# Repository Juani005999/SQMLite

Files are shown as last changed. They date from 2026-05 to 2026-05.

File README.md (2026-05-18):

# SQMLite

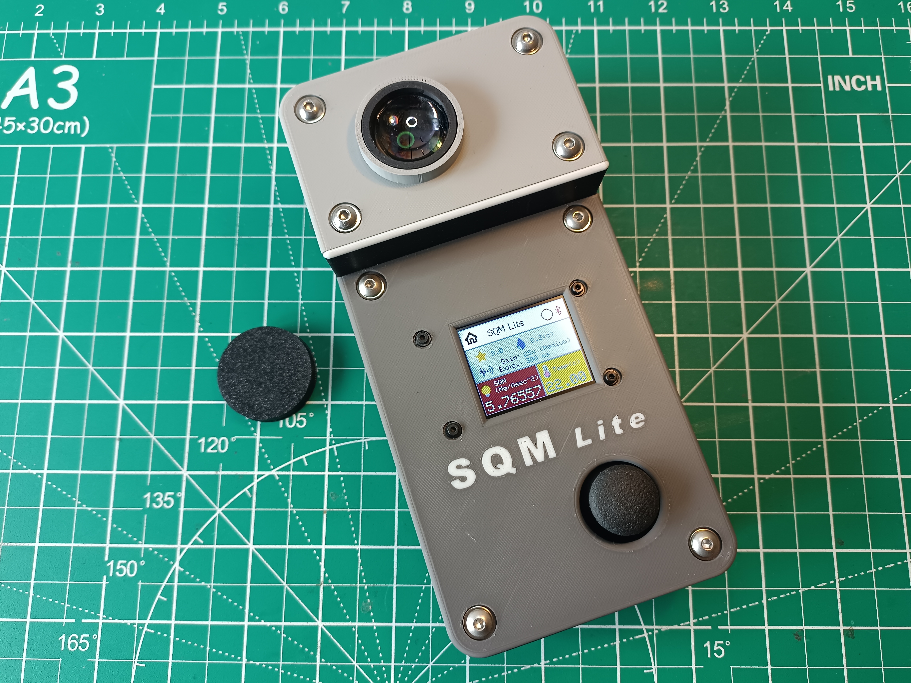
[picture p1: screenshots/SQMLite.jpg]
SQM Lite


## Sommaire
- [Description](#description)
    - [Fonctionnalités](#fonctionnalités)
    - [Echelle de Bortle](#echelle-de-bortle)
- [Liste des pièces](#liste-des-pièces)
    - [Amazon](#amazon)
    - [Ali Express](#ali-express)
    - [Visserie & Divers](#visserie--divers)
- [Montage](#montage)
    - [Breadboard](#breadboard)
    - [PCB](#pcb)
    - [Boxes](#boxes)
    - [ESP32](#esp32)
    - [Capteurs](#capteurs)
    - [Optique du TSL2591](#optique-du-tsl2591)
- [Firmware](#firmware)
    - [Bibliothèques nécessaires à l'application](#bibliothèques-nécessaires-à-lapplication)
    - [Sélection de la carte](#sélection-de-la-carte)
    - [Paramètres de l'application dans Arduino IDE](#paramètres-de-lapplication-dans-arduino-ide)
    - [Configuration de l'application](#configuration-de-lapplication)
    - [Configuration de l'écran TFT ST7735](#configuration-de-lécran-tft-st7735)
    - [Implémentation](#implémentation)
    - [Mode \"Debug\"](#mode-debug)
- [Utilisation](#utilisation)
    - [Matériel](#matériel)
    - [Calibration](#calibration)
    - [Mise en veille](#mise-en-veille)
    - [Logiciel](#logiciel)
        - [En-tête](#en-tête)
        - [Ecran d'accueil](#ecran-daccueil)
        - [Ecran Luminosité](#ecran-luminosité)
        - [Ecran Environnement](#ecran-environnement)
- [Driver ASCOM](#driver-ascom)
    - [Installation](#installation)
    - [Détection du périphérique bluetooth dans Windows](#détection-du-périphérique-bluetooth-dans-windows)
    - [Utilisation dans NINA](#utilisation-dans-nina)
        - [Sélection du SQMLite dans NINA](#sélection-du-sqmlite-dans-nina)
        - [Première utilisation dans NINA](#première-utilisation-dans-nina)
- [Retex](#retex)
- [Révisions](#révisions)

## Description
Le **SQM Lite** est un Sky Quality Meter (SQM) DIY (Do It Yourself) contenant les composants suivant :
- TSL2591
- BME280
- TFT ST7735

Ce modèle est basé sur le [**ROM V2**](https://github.com/Juani005999/ROMV2), sans le GPS, l'accéléromètre et la lecture de la température du ciel.

<p align="right"><a href="#sommaire">Retour au sommaire</a></p>

### Fonctionnalités

- Lecture de la luminosité (full / ir / visible), calcul de la quantité de Lux, du SQM et du Bortle.
- Lecture de la luminosité dans une tâche dédiée FreeRTOS s'exécutant en paralèlle sur le 2ème coeur de l'ESP 32.
- Correction thermique de la lecture du Lux en fonction de la température ambiante.
- Moyenne mobile du Lux sur 50 valeurs permettant de réduire l'incertitude mesurée. Calcul du SQM et du Bortle sur la moyenne mobile du Lux.
- Possibilité de remise à zéro de la moyenne mobile.
- Réglage automatique de la sensibilité (1x, 25x, 428x, 9876x) et de la durée de mesure (100ms, 200ms, 300ms, 400ms, 500ms, 600ms) du capteur de luminosité TSL2591.
- Lecture des conditions d'environnement (température, taux d'humidité, pression atmosphérique) via le capteur BME280.
- Calcul du point de rosée.
- Connection Bluetooth BLE.
- Driver ASCOM permettant de se connecter via Bluetooth BLE.
- Indicateur de mesure de luminosité en cours.
- Indicateur d'état d'une connection Bluetooth BLE client.
- Indicateur de charge restante dans la batterie.
- Mise en veille de l'écran après 5 minutes d'inactivité ou sur demande.

<p align="right"><a href="#sommaire">Retour au sommaire</a></p>

### Echelle de Bortle

Voici l'échelle de Bortle utilisée dans l'application.

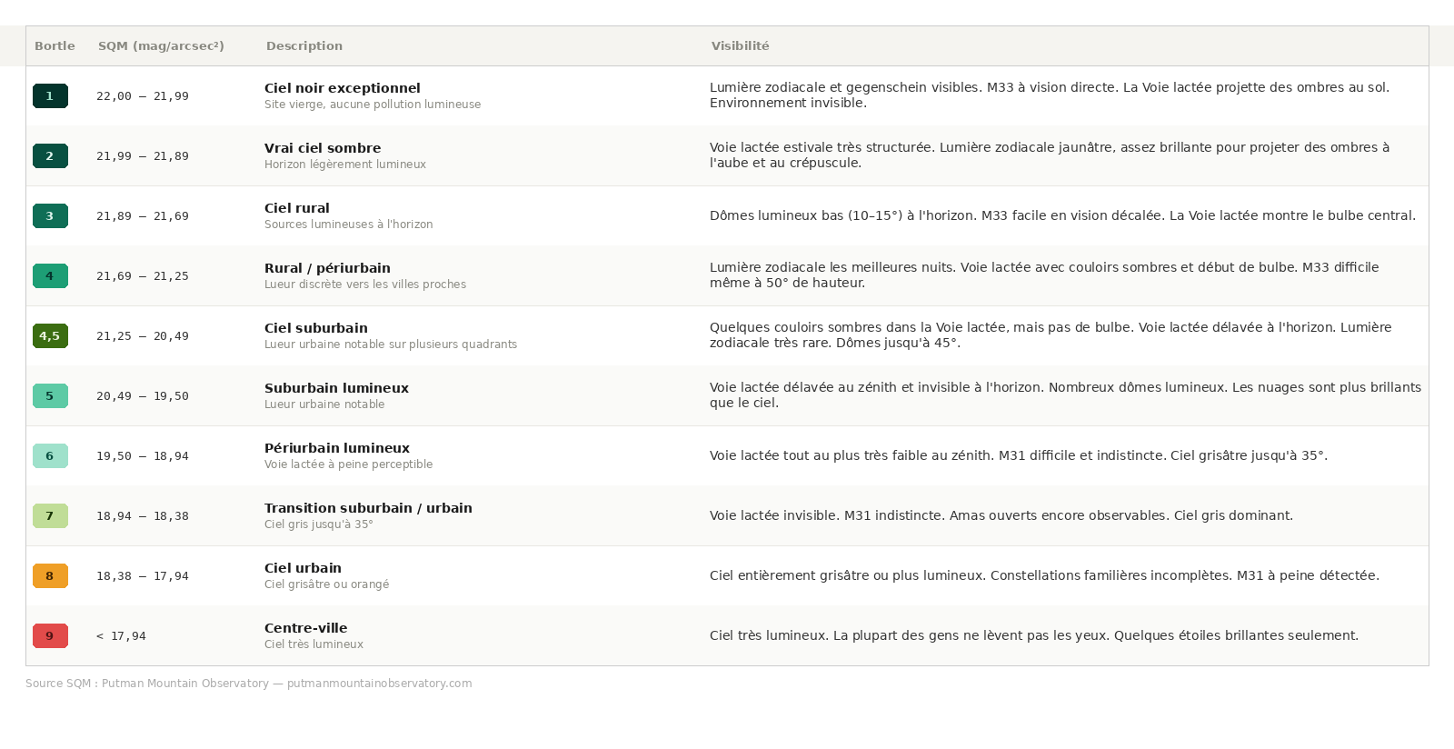
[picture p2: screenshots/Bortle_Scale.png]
Bortle Scale


<p align="right"><a href="#sommaire">Retour au sommaire</a></p>

## Liste des pièces
### Amazon

| Composant | Prix | Nb. pièces | Prix unitaire |
| --- | --- | --- | --- |
| ESP32 with Battery (USB-C) | 18.77 € | 1 | 18.77 € |
| [TSL2591](https://www.amazon.fr/dp/B0GGD3FNKM) | 12.69 € | 1 | 12.69 € |
| [BME280](https://www.amazon.fr/dp/B07HMQMW6M) | 39.48 € | 5 | 7.90 € |
| [TFT ST7735](https://www.amazon.fr/AZDelivery-TFT-Compatible-Raspberry-incluant/dp/B07TJGF8HS) | 27.99 € | 5 | 5.60 € |
| [Lentille D23 F30](https://www.amazon.fr/Lentille-biconvexe-Double-Convexe-Optique/dp/B0GVHDZD22) | 25.94 € | 1 | 25.94 € |
| [Joystick](https://www.amazon.fr/Gebildet-Joystick-Commande-Contr%C3%B4leur-Raspberry/dp/B0DPMN19G6) | 10.99 € | 8 | 1.37 € |
| [Boot Button](https://www.amazon.fr/dp/B07S1MNB8C) | 10.99 € | 5 | 2.20 € |
| [Interrupteur à bascule](https://www.amazon.fr/dp/B076VKRKQQ) | 7.49 € | 5 | 1.50 € |
| [Rallonge USB-C](https://www.amazon.fr/Cablecc-3-1-type-femelle-donn%C3%A9es-dextension/dp/B075P2FF7L) | 17.56 € | 1 | 17.56 € |
| [Testeur de capacité](https://www.amazon.fr/dp/B0DKHT664R) | 12.79 € | 4 | 3.20 € |
| | | Total | **96.73 €** |

<p align="right"><a href="#sommaire">Retour au sommaire</a></p>

### Ali Express
| Composant | Prix | Nb. pièces | Prix unitaire |
| --- | --- | --- | --- |
| [ESP32 with Battery (USB-C)](https://fr.aliexpress.com/item/1005007579177706.html) | 5.09 € | 1 | 5.09 € |
| [TSL2591](https://fr.aliexpress.com/item/1005009222536594.html) | 3.79 € | 1 | 3.79 € |
| [BME280](https://fr.aliexpress.com/item/1005010256393146.html) | 4.59 € | 1 | 4.59 € |
| [TFT ST7735](https://fr.aliexpress.com/item/1005008974306385.html) | 3.29 € | 1 | 3.29 € |
| [Lentille D23 F30](https://fr.aliexpress.com/item/1005007033633969.html) | 2.33 € | 1 | 2.33 € |
| [Joystick](https://fr.aliexpress.com/item/1005009009852719.html) | 0.46 € | 1 | 0.46 € |
| [Boot Button](https://fr.aliexpress.com/item/1005007876916629.html) | 26.19 € | 20 | 1.31 € |
| [Interrupteur à bascule](https://fr.aliexpress.com/item/1005010311259797.html) | 1.79 € | 10 | 0.18 € |
| [Rallonge USB-C 0.2m](https://fr.aliexpress.com/item/1005005292730047.html) | 1.71 € | 1 | 1.71 € |
| [Testeur de capacité](https://fr.aliexpress.com/item/1005006350742151.html) | 1.45 € | 1 | 1.45 € |
| | | Total | **24.20 €** |

<p align="right"><a href="#sommaire">Retour au sommaire</a></p>

### Visserie & Divers

| Composant | Propriétés | Quantité |
| --- | --- | --- |
| Vis & rondelles | M4 x 20mm | 8 |
| Vis & rondelles | M2 x 20mm | 4 |
| Vis & rondelles | M2 x 8mm | 21 |
| Vis & rondelles | M2 x 6mm | 8 |
| Ecrou Nylstop autobloquants | M2 | 7 |
| [PCB EPLZON](https://www.amazon.fr/dp/B0B5DCHM7K) | ... | 1 |
| [Câbles Dupont](https://www.amazon.fr/Breadboard-Jumper-Wires-Dupont-Cable/dp/B0BTT48V7P) | ... | ... |
| [PCB Vis Connecteur](https://www.amazon.fr/dp/B082ZNRQMJ?th=1) | ... | ... |
| [Jumper Breadboard](https://www.amazon.fr/dp/B0F6LJS4L2?ref=ppx_yo2ov_dt_b_fed_asin_title) | ... | ... |
| [Pile Rechargeable 18650](https://bestpiles.fr/piles-rechargeables-18650/991-pile-rechargeable-18650-inr18650mj1-li-ion-37v-3500mah-10a-8438493099829.html) | Li-ion 3,7V 3500mAh 10A | 1 |

<p align="right"><a href="#sommaire">Retour au sommaire</a></p>

## Montage

Montage

<p align="right"><a href="#sommaire">Retour au sommaire</a></p>

### Breadboard
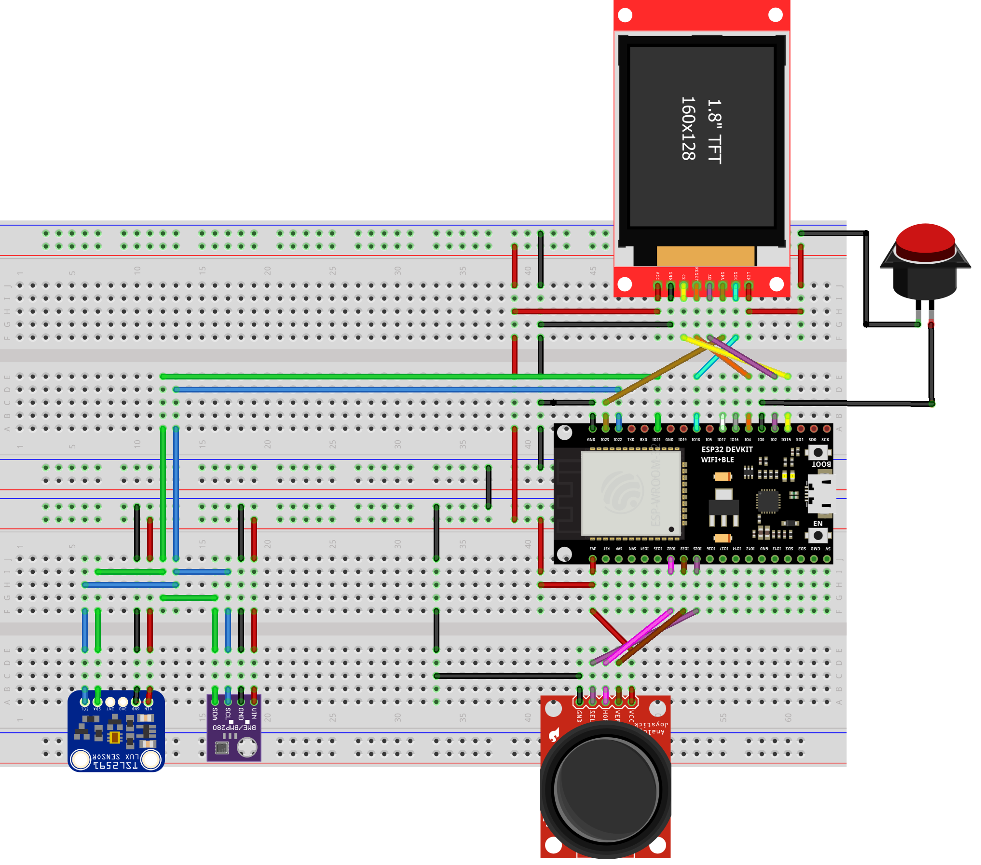
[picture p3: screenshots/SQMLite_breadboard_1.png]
Breadboard


<p align="right"><a href="#sommaire">Retour au sommaire</a></p>

### PCB
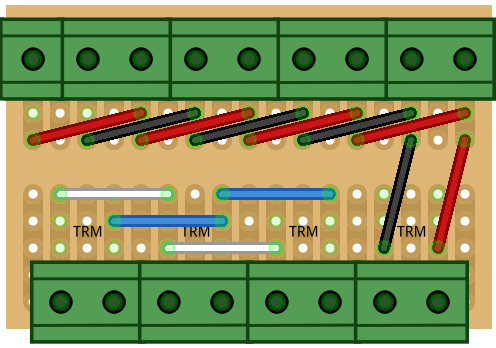
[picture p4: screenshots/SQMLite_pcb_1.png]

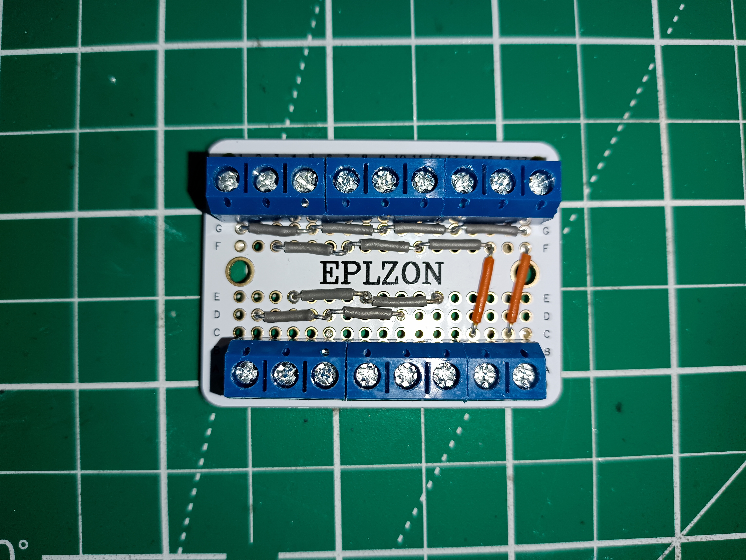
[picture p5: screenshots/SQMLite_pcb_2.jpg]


<p align="right"><a href="#sommaire">Retour au sommaire</a></p>

### Boxes
Vous trouverez dans [ce dossier](./Boxes/) tous les fichiers STL nécessaires à l'impression 3D.

<p align="right"><a href="#sommaire">Retour au sommaire</a></p>

### ESP32
Des branchements direct sur l'ESP32 sont nécessaires :
- 2 câbles Dupont branchés directement sur l'interrupteur de l'ESP et connectés à l'interrupteur du **SQM Lite**.
- 2 câbles branchés sur les pôles + et - de l'ESP et connectés à l'indicateur de charge restante de la batterie.

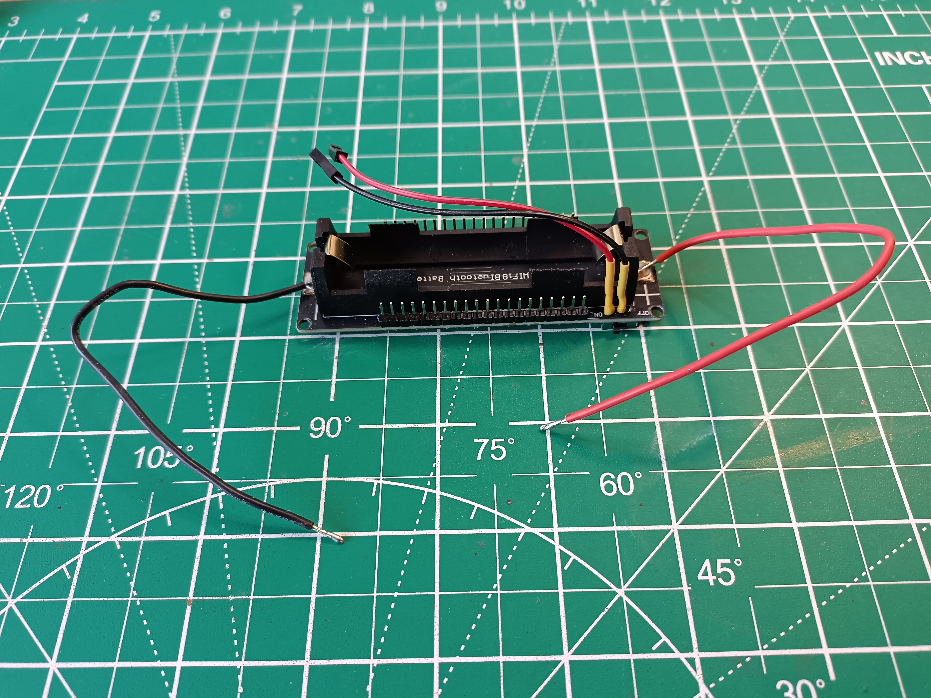
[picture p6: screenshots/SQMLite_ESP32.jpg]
ESP32


> [!WARNING]
> Attention, le connecteur **USB-C** présent sur l'ESP est **très très fragile** (j'en ai personnellement cassé plusieurs sur d'autres projets en faisant des branchements). Je vous conseil donc de rajouter 2 points de soudure de part et d'autre du connecteur  afin d'augmenter sa solidité.

<p align="right"><a href="#sommaire">Retour au sommaire</a></p>

### Capteurs
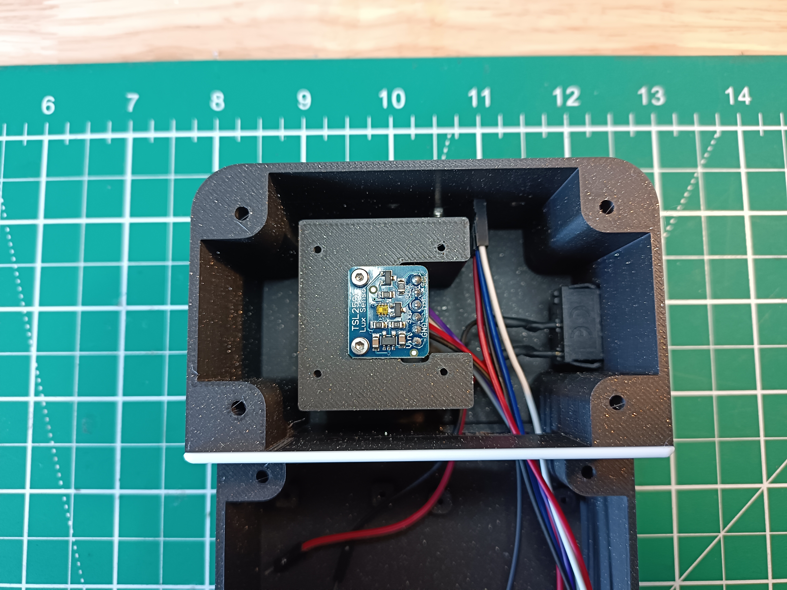
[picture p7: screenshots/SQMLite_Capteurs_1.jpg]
Capteurs

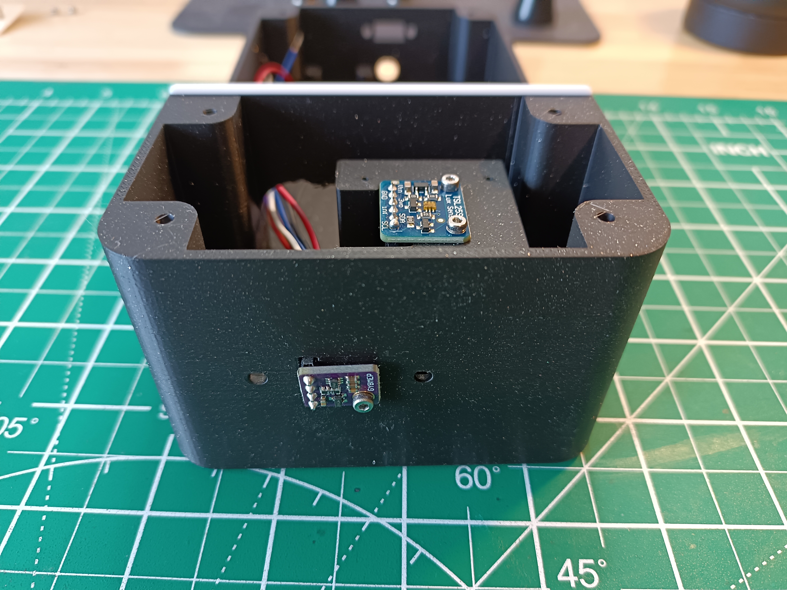
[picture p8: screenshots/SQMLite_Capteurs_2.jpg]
Capteurs

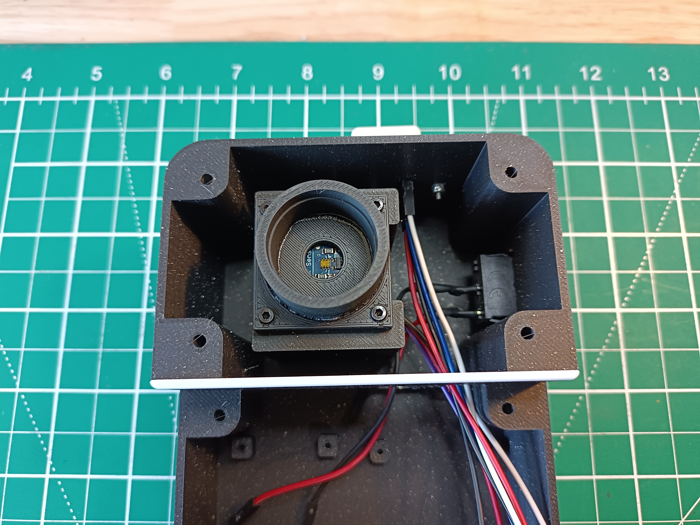
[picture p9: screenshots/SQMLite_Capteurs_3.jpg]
Capteurs

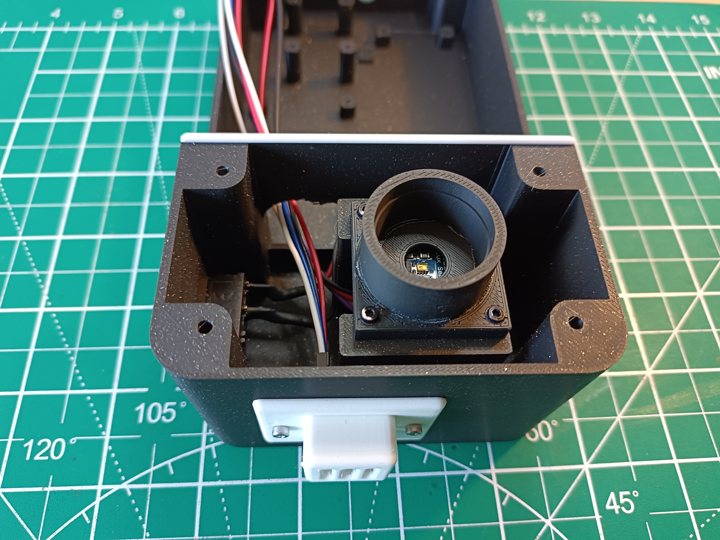
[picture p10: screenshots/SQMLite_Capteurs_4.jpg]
Capteurs


<p align="right"><a href="#sommaire">Retour au sommaire</a></p>

#### Optique du TSL2591
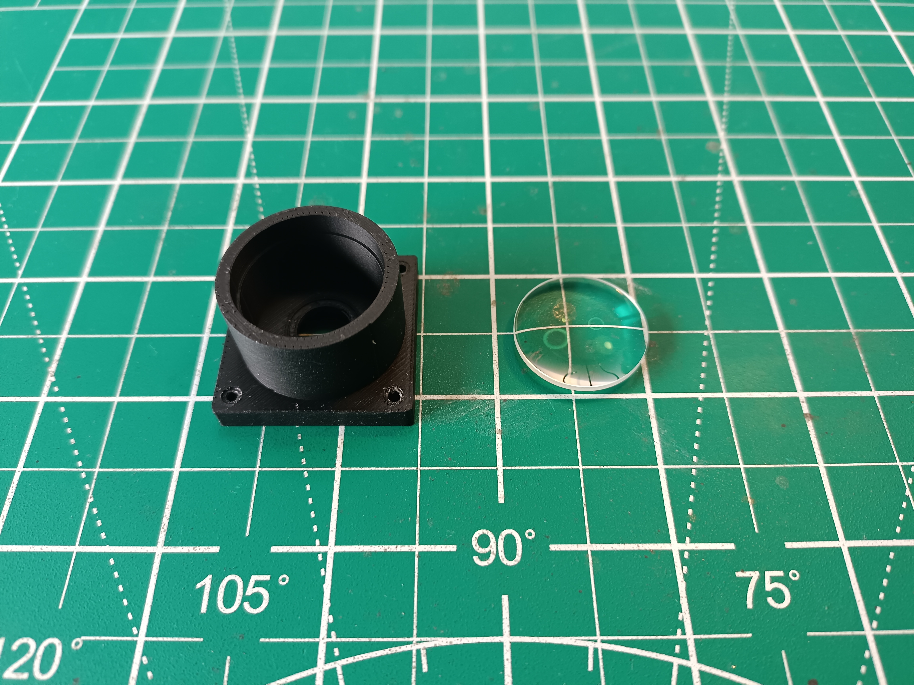
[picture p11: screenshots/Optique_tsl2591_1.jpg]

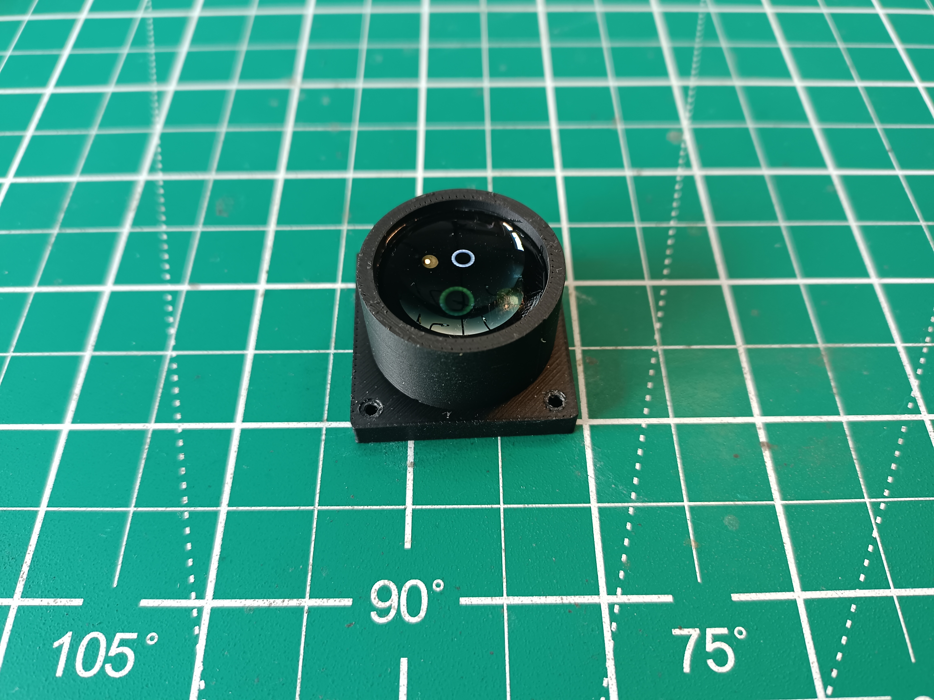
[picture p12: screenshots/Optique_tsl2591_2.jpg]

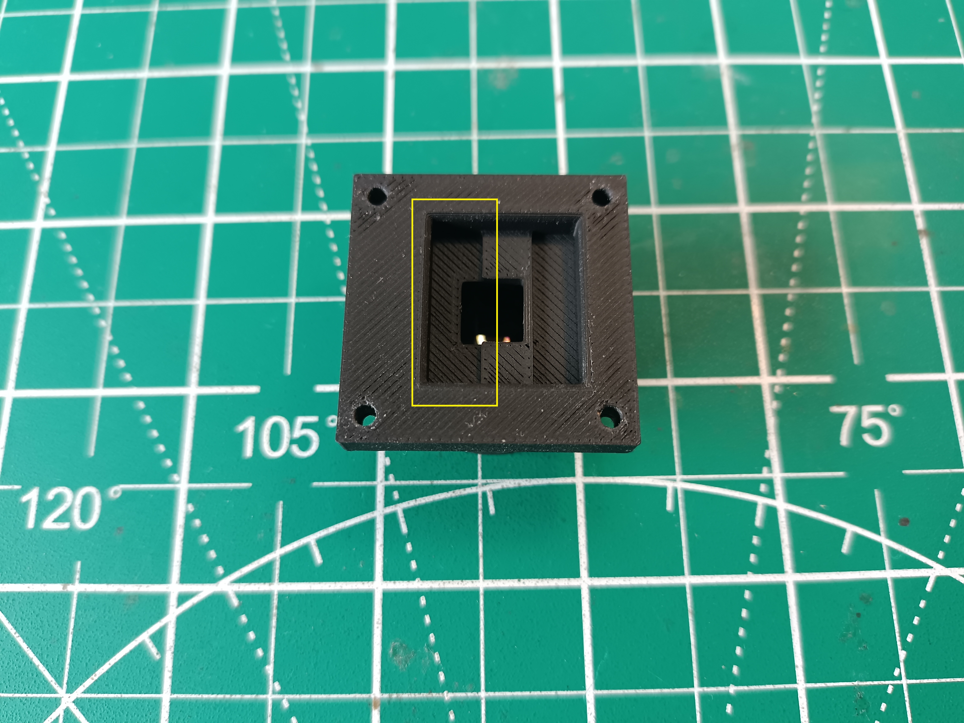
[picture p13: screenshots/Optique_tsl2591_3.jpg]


> [!IMPORTANT]
> La partie encadrée en jaune correspond au côté des vis du TSL2591.

> [!TIP]
> La lentille est optionnelle. Vous pouvez uniquement positionner le cache du capteur et le tube sans la lentille. Vous pourrez ensuite corriger la [calibration](#calibration) si nécessaire.

<p align="right"><a href="#sommaire">Retour au sommaire</a></p>

## Firmware

- Télécharger le fichier **SQMLite_Firmware.zip**
- Depuis votre Arduino IDE, installer la bibliothèque **SQMLite**, en sélectionnant le fichier téléchargé via le menu : \
***Croquis*** -> ***Importer une bibliothèque*** -> ***Ajouter la bibliothèque .ZIP ...***

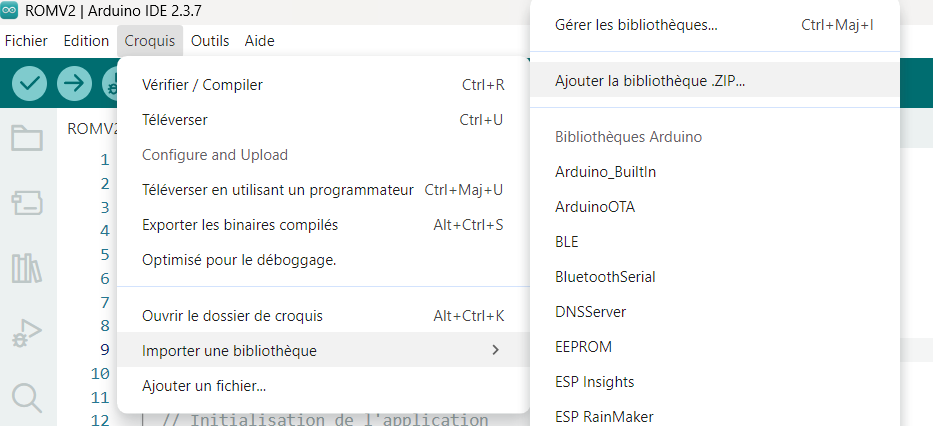
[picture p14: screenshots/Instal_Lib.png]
ROMV2_LIB


<p align="right"><a href="#sommaire">Retour au sommaire</a></p>

### Bibliothèques nécessaires à l'application
Voici la liste des bibliothèques utilisées par l'application que vous devez installer via le gestionnaire de librairies dans votre *Arduino IDE* :

- Adafruit_TSL2591
- Adafruit_BME280
- TFT_eSPI

<p align="right"><a href="#sommaire">Retour au sommaire</a></p>

### Sélection de la carte
Dans votre *Arduino IDE*, sélectionnez la carte **ESP32 Dev Module**.
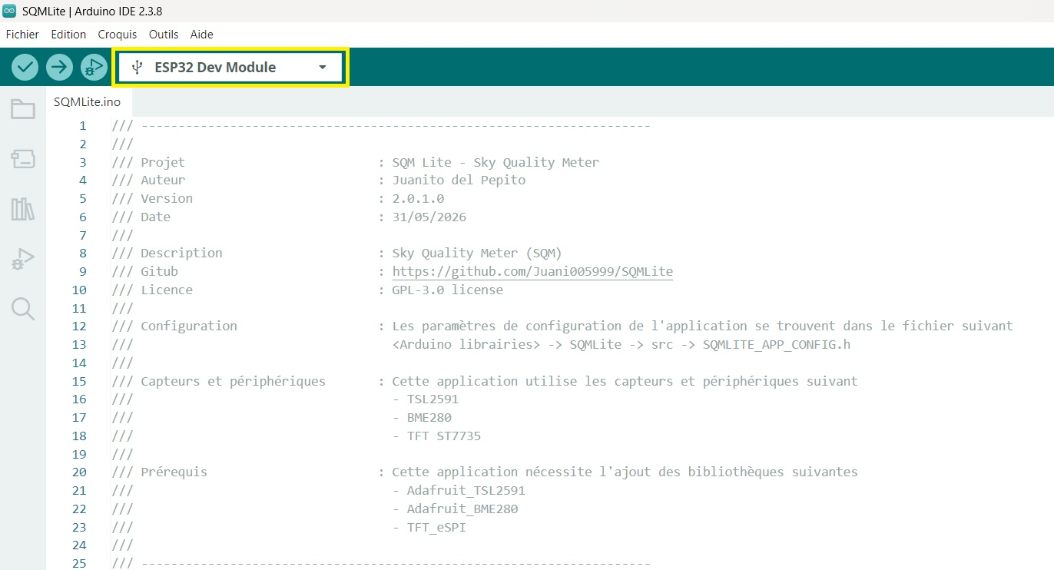
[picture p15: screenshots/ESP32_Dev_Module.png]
ESP32 Dev Module


<p align="right"><a href="#sommaire">Retour au sommaire</a></p>

### Paramètres de l'application dans Arduino IDE

> [!WARNING]
> Attention : l'application nécessite de se positionner en mode **"Huge App"** (cf. image ci-dessous), permettant ainsi de disposer de l'espace mémoire suffisant pour le fonctionnement sur l'ESP32.

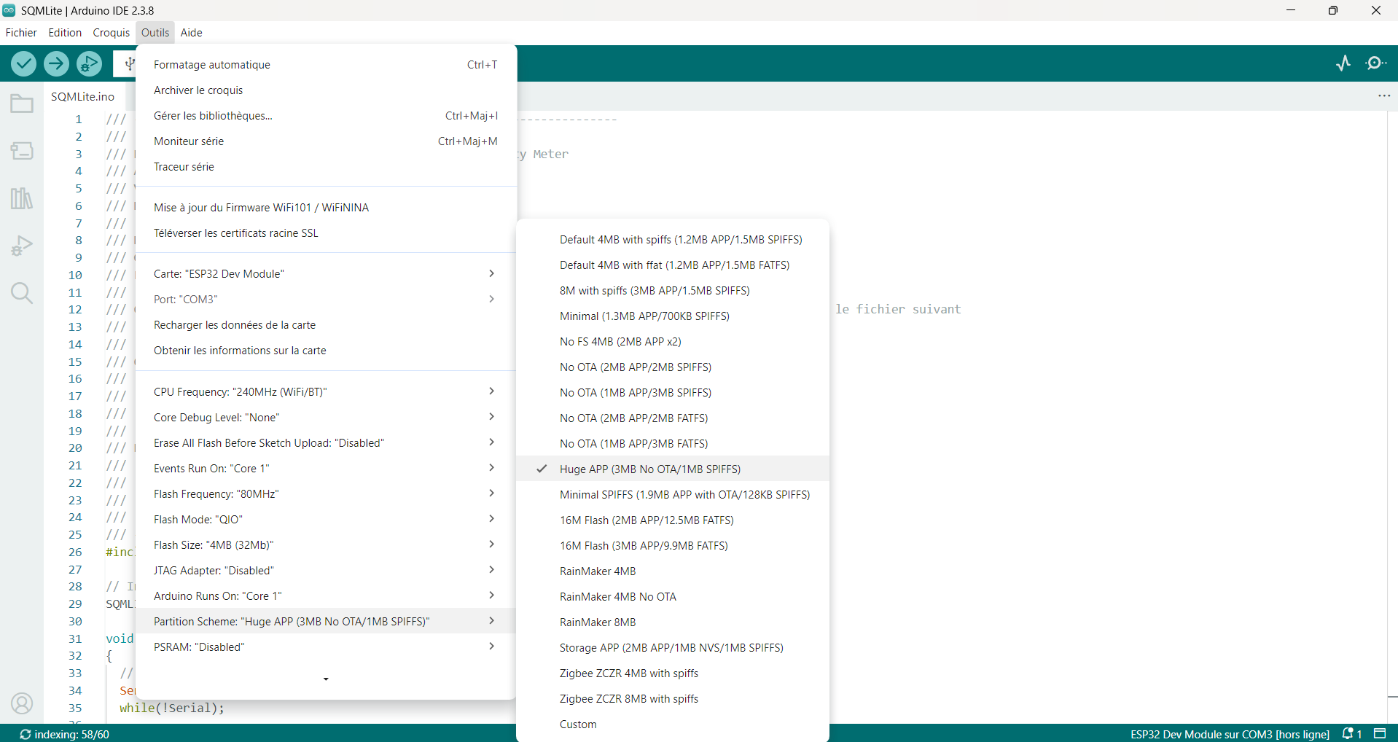
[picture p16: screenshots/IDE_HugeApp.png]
Arduino IDE Huge App


<p align="right"><a href="#sommaire">Retour au sommaire</a></p>

### Configuration de l'application
Vous pouvez accéder à la configuration de l'application via le fichier suivant : \
\<***Arduino librairies***\> -> ***SQMLite*** -> ***src*** -> ***SQMLITE_APP_CONFIG.h***

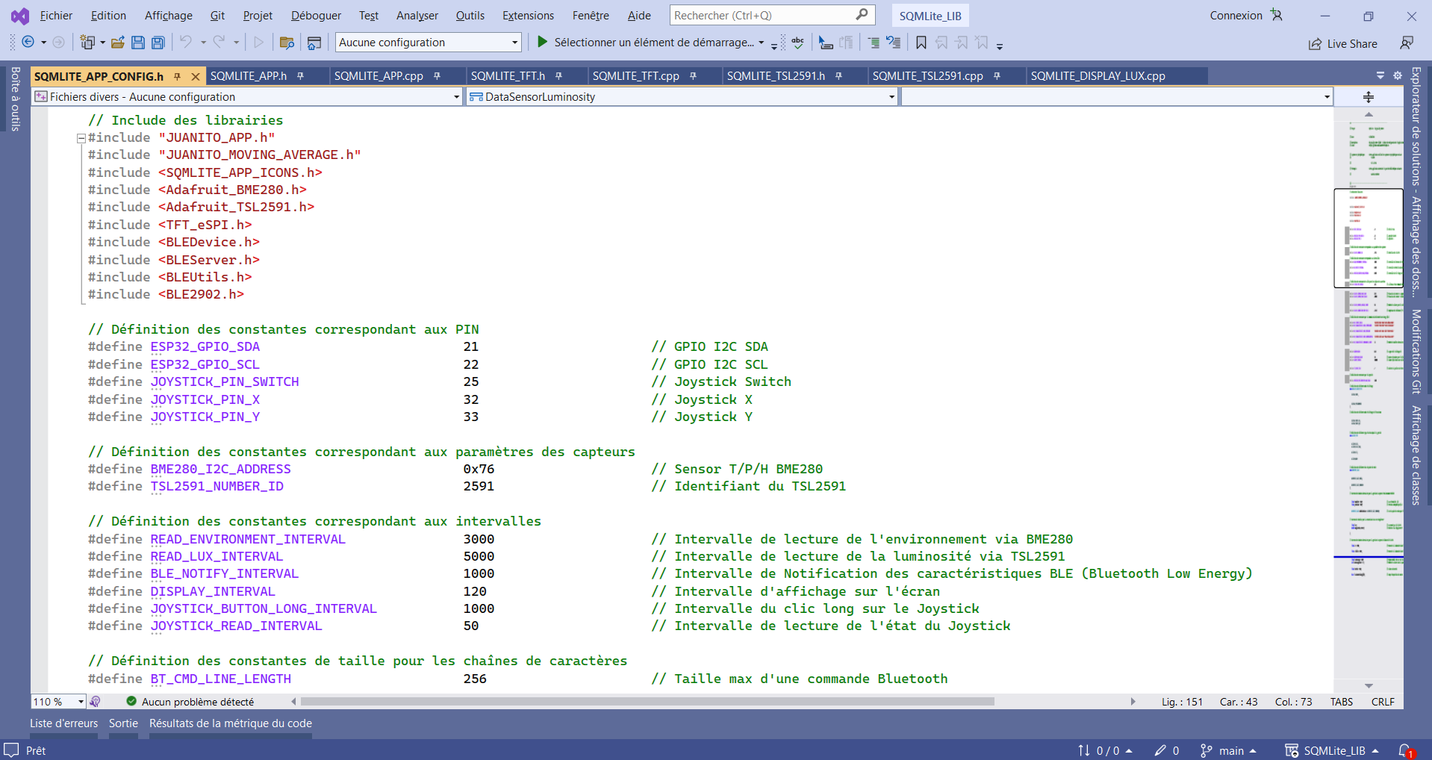
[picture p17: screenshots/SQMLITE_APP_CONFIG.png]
SQMLITE_APP_CONFIG.h


<p align="right"><a href="#sommaire">Retour au sommaire</a></p>

### Configuration de l'écran TFT ST7735
Afin de faire fonctionner votre écran, il vous sera nécessaire de le configurer via la bibliothèque **TFT_eSPI** en modifiant le fichier suivant : \
\<***Arduino librairies***\> -> ***TFT_sSPI*** -> ***User_Setup.h***

Vous devez modifier 2 paramètres :

- La sélection de votre écran :
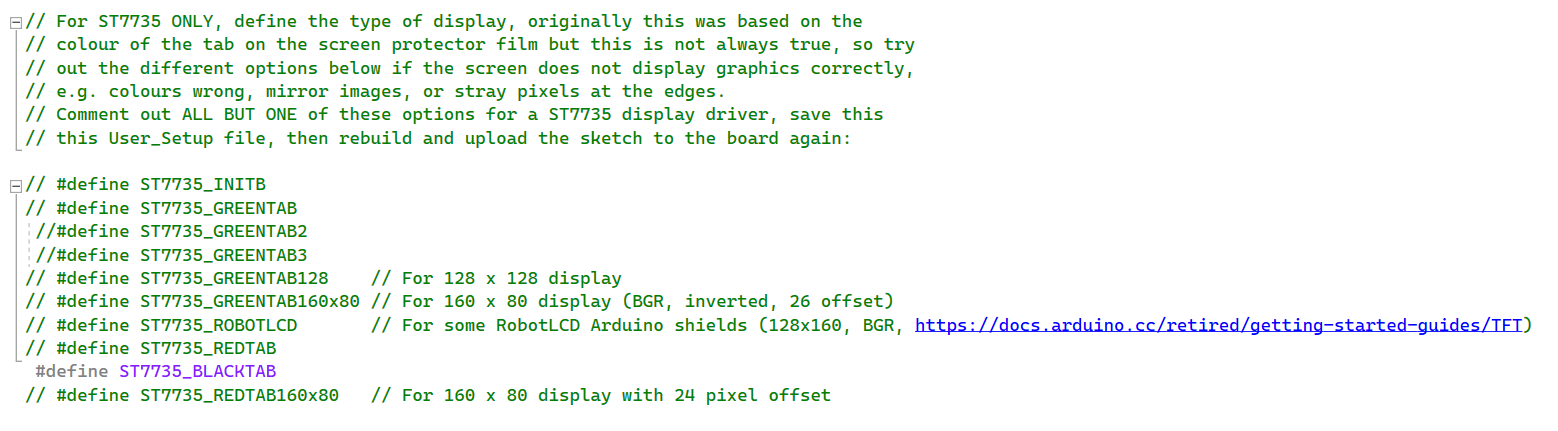
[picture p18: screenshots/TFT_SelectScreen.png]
TFT_eSPI Select Screen

- Les PINs associés à votre écran :
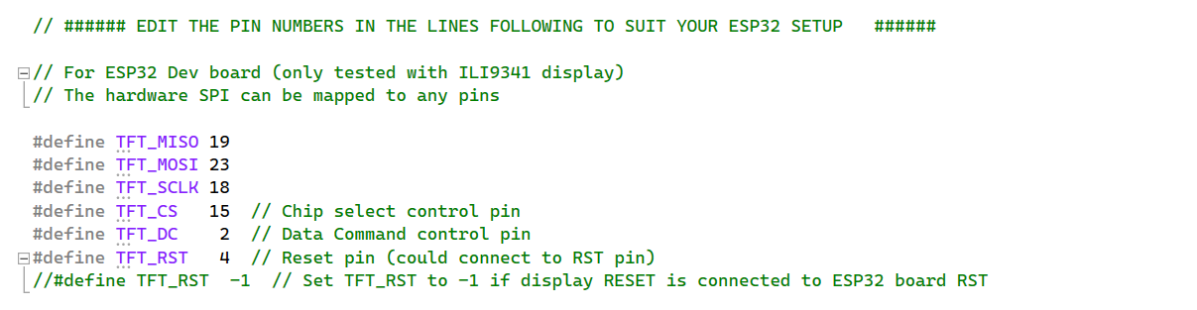
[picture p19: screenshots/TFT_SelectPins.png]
TFT_eSPI Select PINs


<p align="right"><a href="#sommaire">Retour au sommaire</a></p>

### Implémentation
Pour démarrer un nouveau projet SQMLite, il vous suffit d'aller dans les examples de votre Arduino IDE, et de sélectionner **SQMLite**.

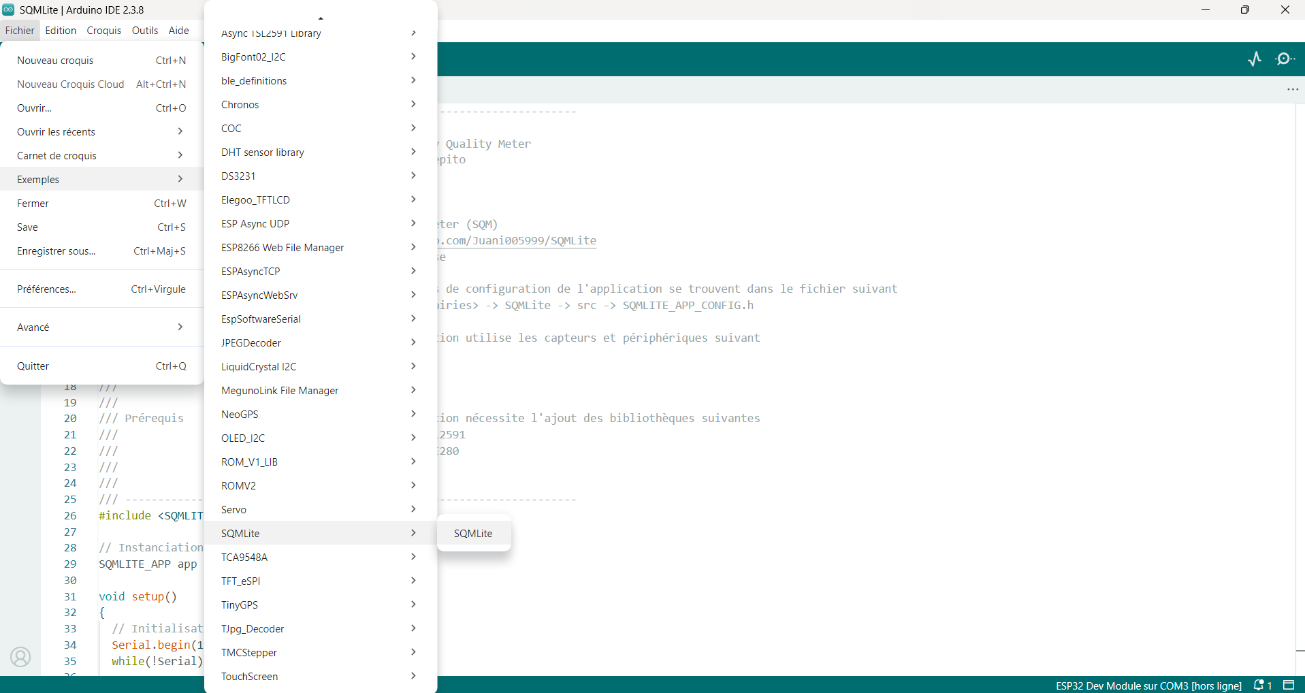
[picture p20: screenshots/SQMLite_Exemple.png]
SQMLite Application example


<p align="right"><a href="#sommaire">Retour au sommaire</a></p>

### Mode \"Debug\"
Pendant le développement de votre projet, vous pouvez activer le mode **Debug**.

> [!WARNING]
> Afin d'améliorer les performances, **n'oubliez pas de le désactiver une fois le fois le projet abouti**.

Dans le fichier suivant : \
\<***Arduino librairies***\> -> ***SQMLite*** -> ***src*** -> ***JUANITO_APP.h*** \
Enlevez les commentaires devant la ligne : \
`#define DEBUG`

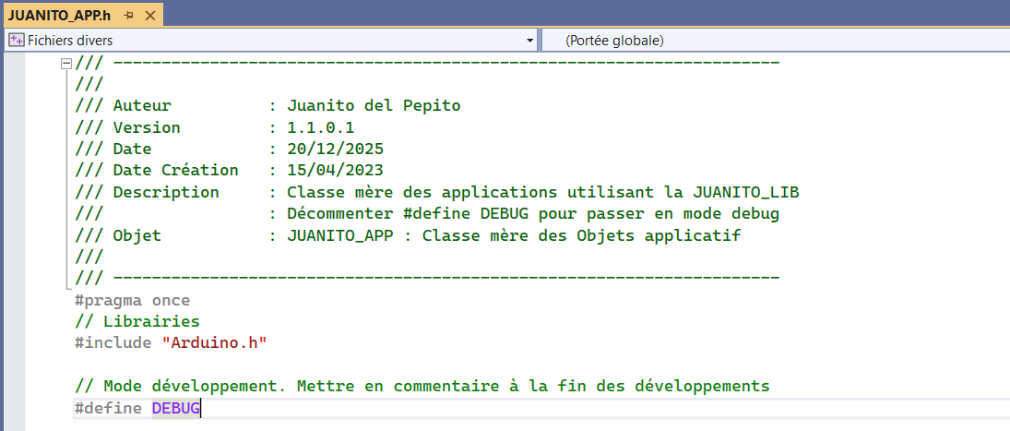
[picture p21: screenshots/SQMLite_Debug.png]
SQMLite Debug


En activant le mode **Debug**, vous pourrez voir les traces de l'application dans le *Moniteur série* de votre *Arduino IDE* pendant l'exécution. 

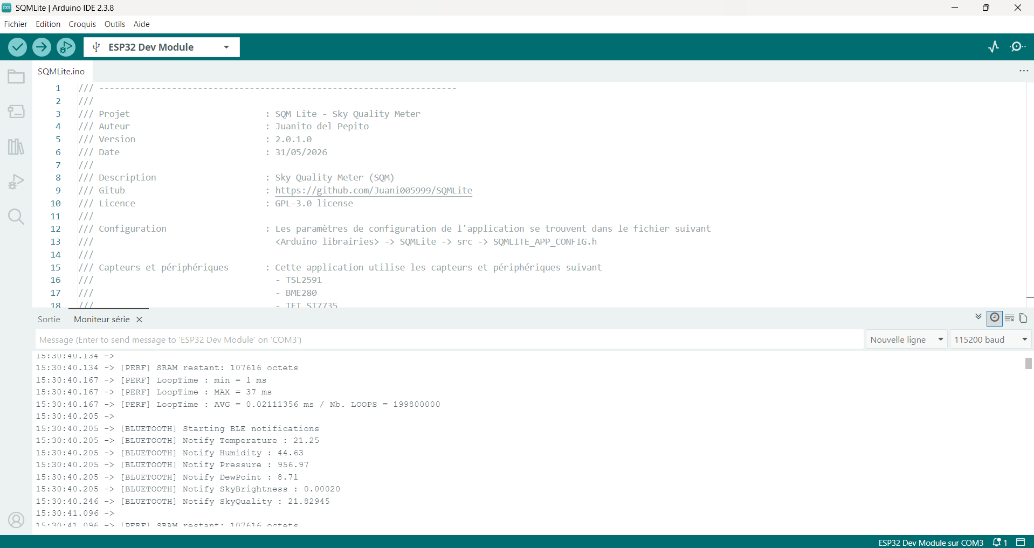
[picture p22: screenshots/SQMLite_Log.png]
SQMLite Logs


<p align="right"><a href="#sommaire">Retour au sommaire</a></p>

## Utilisation

### Matériel
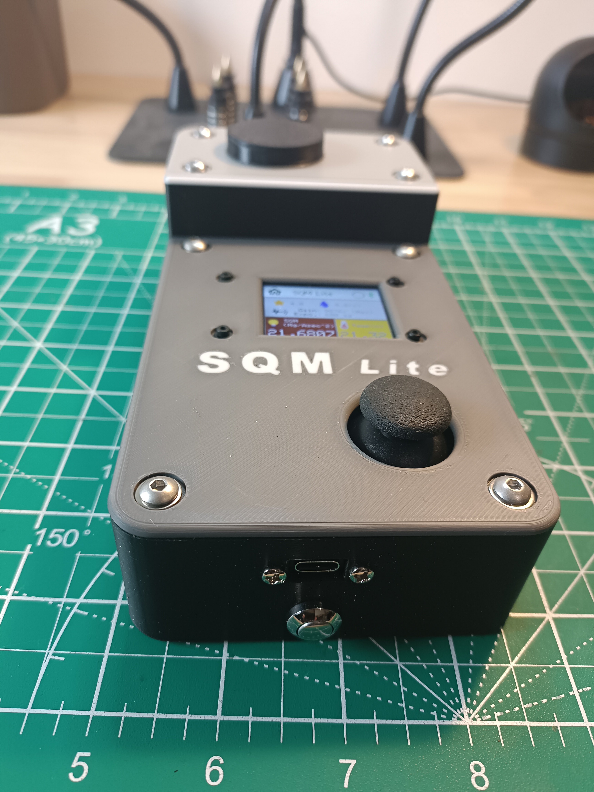
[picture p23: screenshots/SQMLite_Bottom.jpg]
ROMV2 Bottom

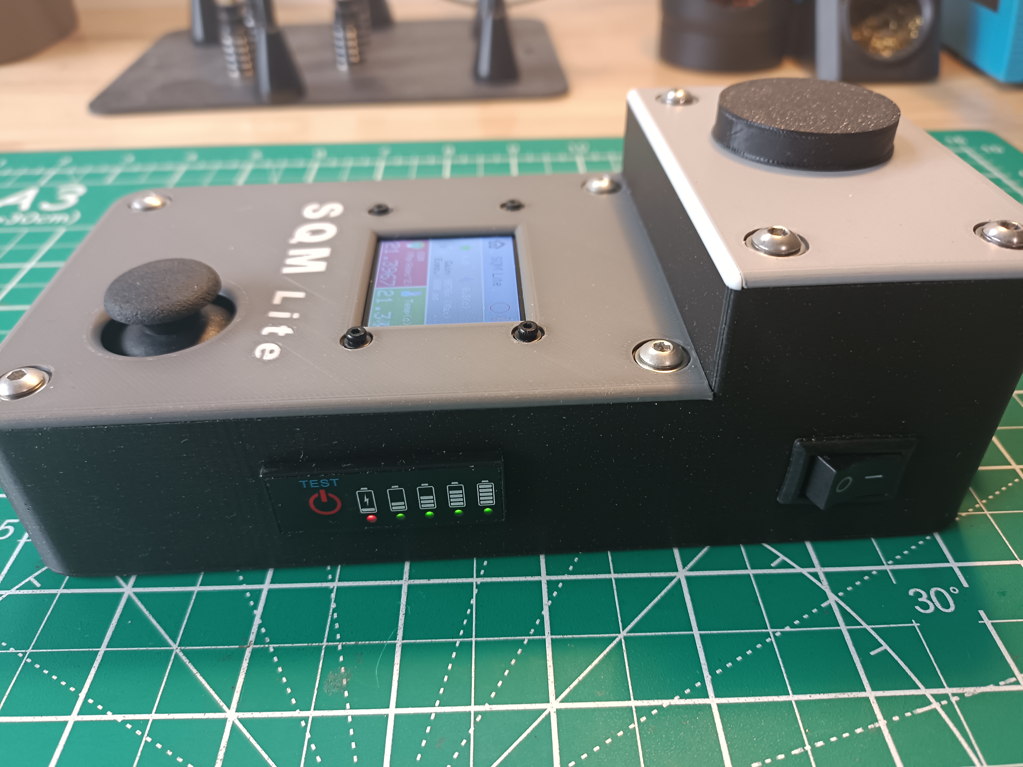
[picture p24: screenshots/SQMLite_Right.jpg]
ROMV2 Right


Vous trouverez au bas du **SQMLite** :
- 1 connecteur **USB-C** permettant de recharger le **SQMLite** et servant également à la mise à jour du firmware.
- 1 interrupteur (bouton poussoir) permettant de mettre l'ESP en mode Boot lors de la mise à jour du firmware.

Vous trouverez sur le côté droit du **SQMLite** :
- l'interrupteur On/Off de l'appareil.
- L'indicateur de charge restante dans la batterie. Appuyez sur le bouton **"TEST"** de l'indicateur pour connaître la charge restante.

Le pilotage du **SQMLite** s'effectue via le joystick :
- Droite et gauche permettent de naviguer parmis les différents écrans.
- Haut et Bas permettent un retour direct à l'écran d'accueil.
- Sur l'écran d'acceuil, un clic sur le joystick permet d'alterner l'affichage ***Lux*** et ***SQM***.
- Sur l'écran de luminosité, un clic sur le joystick permet de réinitialiser la moyenne mobile en cours.
- Un clic long sur le joystick permet de basculer l'écran en mode veille.

<p align="right"><a href="#sommaire">Retour au sommaire</a></p>

### Calibration

Dans le fichier de configuration, vous trouverez une constante définie permettant de calibrer le **SQMLite** dans sa lecture de luminosité via le TSL2591.
La constante de calibration est : `TSL2591_CALIBRATION`

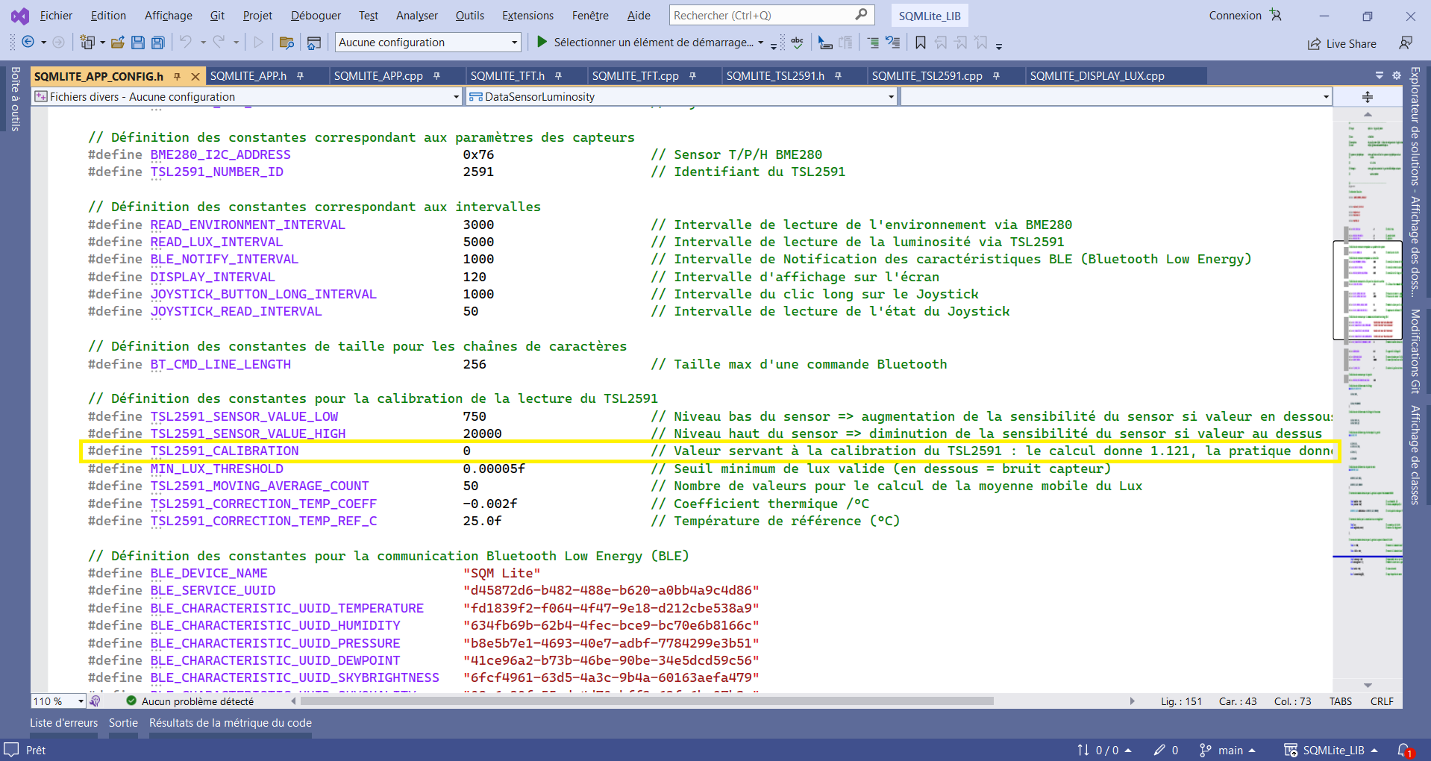
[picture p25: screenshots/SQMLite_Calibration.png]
SQMLite Calibration


> [!TIP]
> La calibration nécessaire avec la lentille donne par le calcul une valeure de 1.121, mais dans la pratique, la valeure de 0 donne des résultats plus cohérents. Vous pouvez également donner des valeurs négatives si nécessaire.

<p align="right"><a href="#sommaire">Retour au sommaire</a></p>

### Mise en veille

L'écran du **SQMLite** s'éteint automatiquement après 5 min d'inactivité (modifiable dans le fichier de configuration).
Cette mise en veille peut être déclenchée à tout moment par un "click long" sur le joystick.

Pour sortir du mode veille, il suffit d'effectuer une action sur le joystick, peu importe laquelle.

<p align="right"><a href="#sommaire">Retour au sommaire</a></p>

### Logiciel

Le firmware est constitué de 3 écrans, avec un en-tête commun à tous les écrans.

#### En-tête

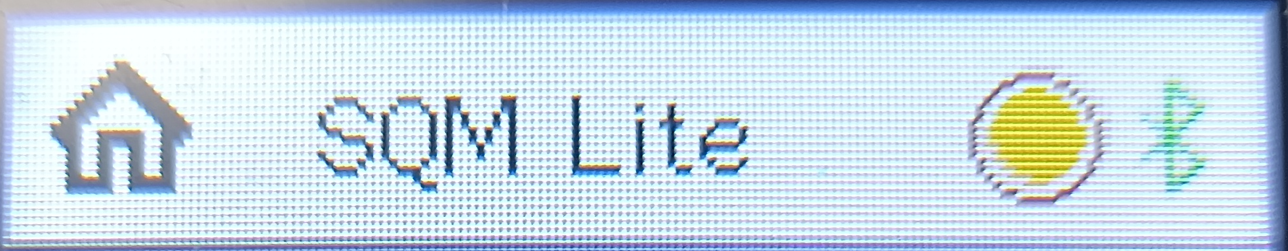
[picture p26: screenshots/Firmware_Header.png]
Header


L'en-tête comprend les éléments suivants :
- Un icone principal spécifique à l'écran en cours d'affichage.
- Le titre de l'application.
- Un icone indiquant qu'une prise de mesure de la luminosité est en cours.
- Un icone indiquant la présence d'une connexion client via Blutooth (2 états : rouge et vert).

<p align="right"><a href="#sommaire">Retour au sommaire</a></p>

#### Ecran d'accueil

L'écran d'accueil comprend les éléments suivants :
- Un icone affichant la valeur de Bortle en cours.
- Un icone représentant le point de rosée ainsi que la température du point de rosée. L'icone à trois états :
    - Bleu : pas de risque de buée.
    - Orange : point de rosée à moins de 5°c de la température ambiante, risque de buée imminente.
    - Rouge : point de rosée atteint, pare-buée obligatoire.
- Le gain du capteur lors de la dernière mesure de luminosité effectuée.
- Le temps d'exposition du capteur lors de la dernière mesure de luminosité effectuée.
- Un espace affichant la valeur de luminosité mesurée. Deux modes d'affichage :
    - Affichage du Lux
    - Affichage du SQM (Mag / Arcsec²).\
> [!TIP]
> On passe d'un mode à l'autre (Lux / SQM) en cliquant sur le joystick.
- Un espace affichant la valeur de la température ambiante.

Screen Home Lux

Screen Home SQM

<p align="right"><a href="#sommaire">Retour au sommaire</a></p>

#### Ecran Luminosité

Screen Lux

L'écran Luminosité comprend les éléments suivants :
- La luminosité mesurée totale et dans les Infrarouge.
- La luminosité mesurée dans le visible.
- La quantité de Lux issue des mesures Ir et Full.
- La quantité de Lux sur une moyenne mobile. Le nombre de mesures permettant de calculer la moyenne est entre parenthèse. Le nombre maximum de valeurs pour le calcul de la moyenne mobile est de 50 (ce nombre est modifiable dans le fichier de configuration via la constante `TSL2591_MOVING_AVERAGE_COUNT`).
- Le SQM (Mag / Arcsec²) calculé à partir du Lux moyen.
- Le Bortle issu de la valeur du SQM calculé.
- Le gain du capteur lors de la dernière mesure de luminosité effectuée.
- Le temps d'exposition du capteur lors de la dernière mesure de luminosité effectuée.

> [!NOTE]
> Le gain et le temps d'exposition du capteur sont ajustés automatiquement par le firmware afin d'avoir les valeurs les plus appropriées en fonction du contexte.

> [!IMPORTANT]
> Pour réinitialiser la moyenne mobile effectuée sur la mesure de Lux, il suffit d'effectuer un **clic sur le joystick**.

<p align="right"><a href="#sommaire">Retour au sommaire</a></p>

#### Ecran Environnement

Screen Lux

L'écran Environnement comprend les éléments suivants :
- La température ambiante (°C).
- Le taux d'humidité (%).
- La pression atmosphérique (Pa).
- Un icone représentant le point de rosée ainsi que la température du point de rosée. L'icone à trois états :
    - Bleu : pas de risque de buée.
    - Orange : point de rosée à moins de 5°c de la température ambiante, risque de buée imminente.
    - Rouge : point de rosée atteint, pare-buée obligatoire.

<p align="right"><a href="#sommaire">Retour au sommaire</a></p>

## Driver ASCOM

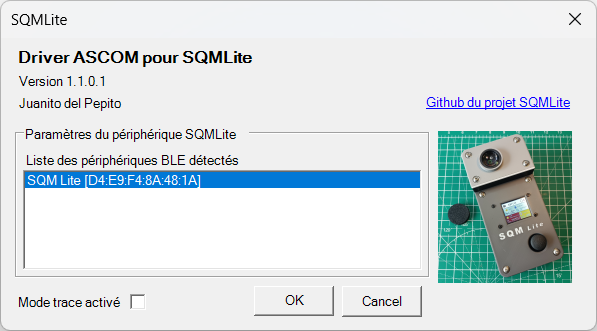
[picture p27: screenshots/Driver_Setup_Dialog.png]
Driver Setup Dialog


### Installation

- Téléchargez et exécutez le fichier **ASCOM driver for SQMLite setup.exe**

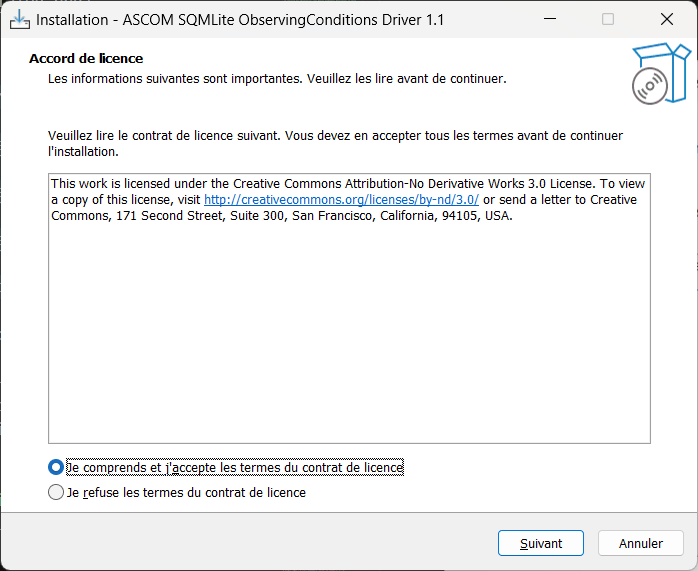
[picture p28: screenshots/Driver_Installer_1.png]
Driver Installer screen 1


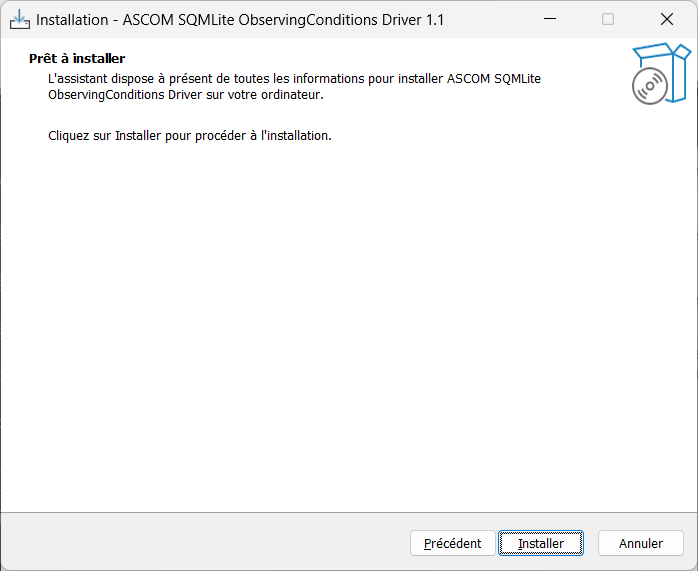
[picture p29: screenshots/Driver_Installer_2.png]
Driver Installer screen 2


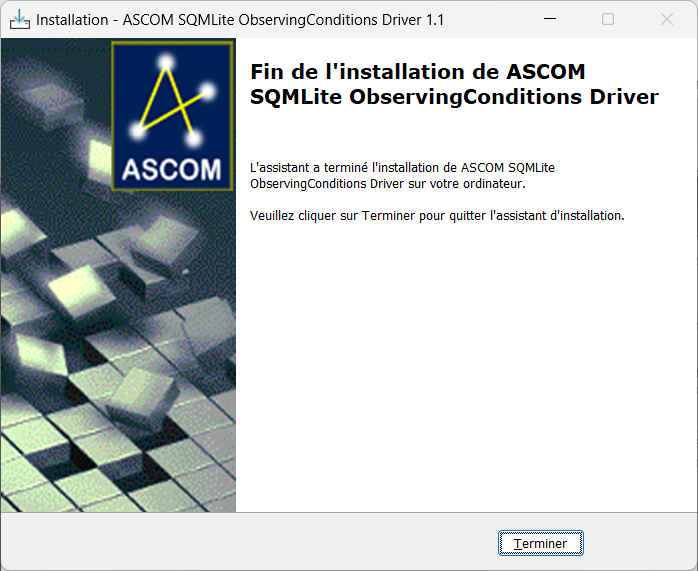
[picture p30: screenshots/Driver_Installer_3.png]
Driver Installer screen 3


<p align="right"><a href="#sommaire">Retour au sommaire</a></p>

### Détection du périphérique bluetooth dans Windows

Afin de pouvoir utiliser le **Driver ASCOM SQMLite** depuis votre application Astro comme N.I.N.A., vous devez au préalable déclarer votre périphérique Bluetooth auprès de votre système Windows.

> [!IMPORTANT]
> Cette opération de reconnaissance de votre périphérique Bluetooth auprès de votre système Windows n'est à faire qu'une seule fois, lors de la première utilisation.

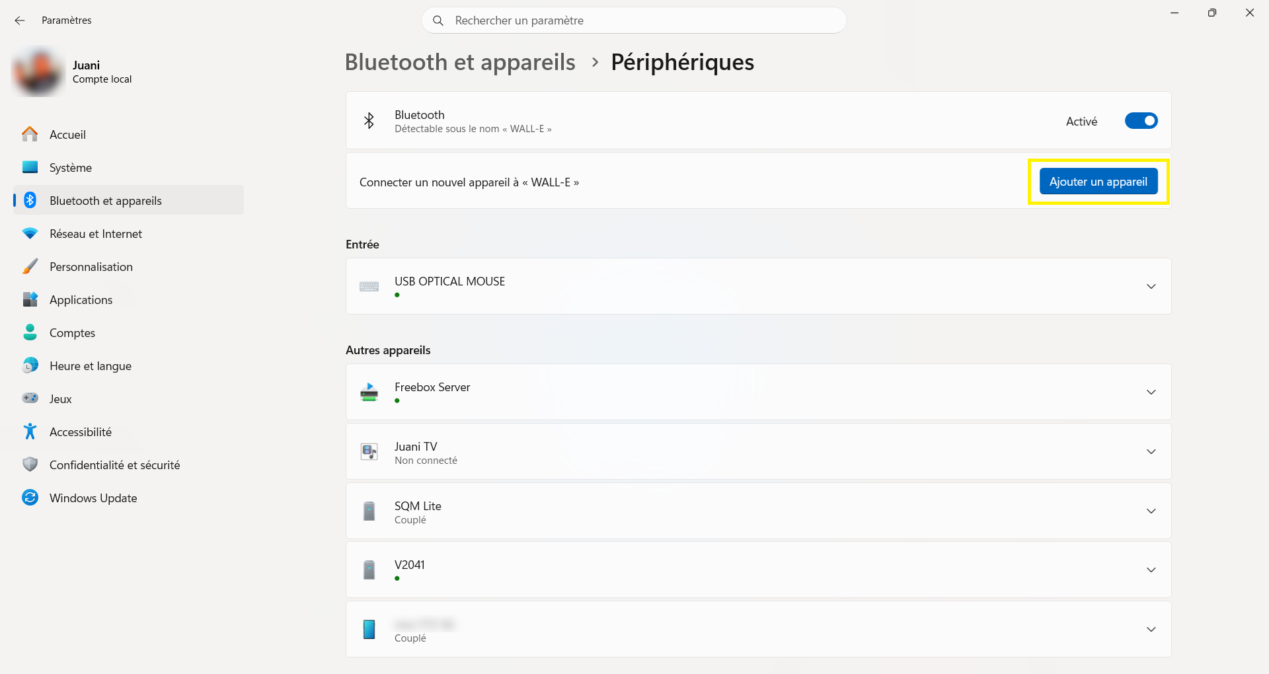
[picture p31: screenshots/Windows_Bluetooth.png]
Windows bluetooth


Dans la fenêtre des paramètres windows, allez dans la section "***Bluetooth et appareils***", si nécessaire, cliquez sur "***Afficher d'autres périphériques***", puis cliquez sur le bouton "***Ajouter un appareil***" et suivez les étapes de l'assistant.

<p align="right"><a href="#sommaire">Retour au sommaire</a></p>

### Utilisation dans NINA

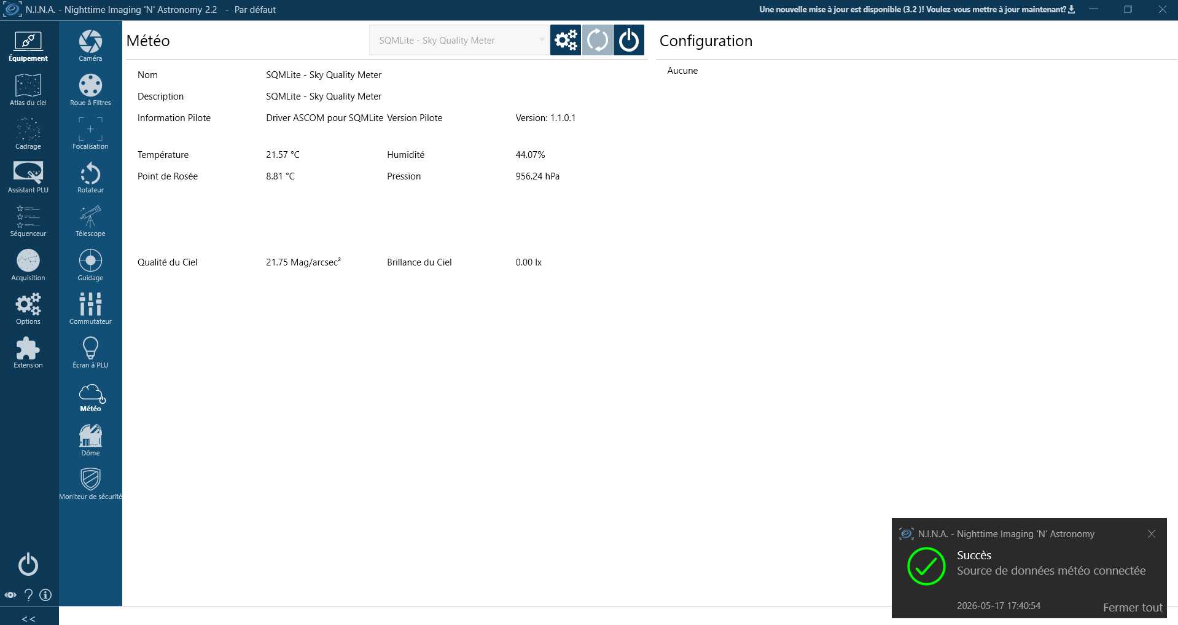
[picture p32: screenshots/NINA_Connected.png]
NINA


#### Sélection du SQMLite dans NINA

Afin de sélectionner le **SQMLite** dans N.I.N.A., allez dans l'onglet "***Equipements***", et dans le sous-onglet "***Météo***".\
Dans la liste déroulante, sélectionnez "***SQMLite - Sky Quality Meter***"

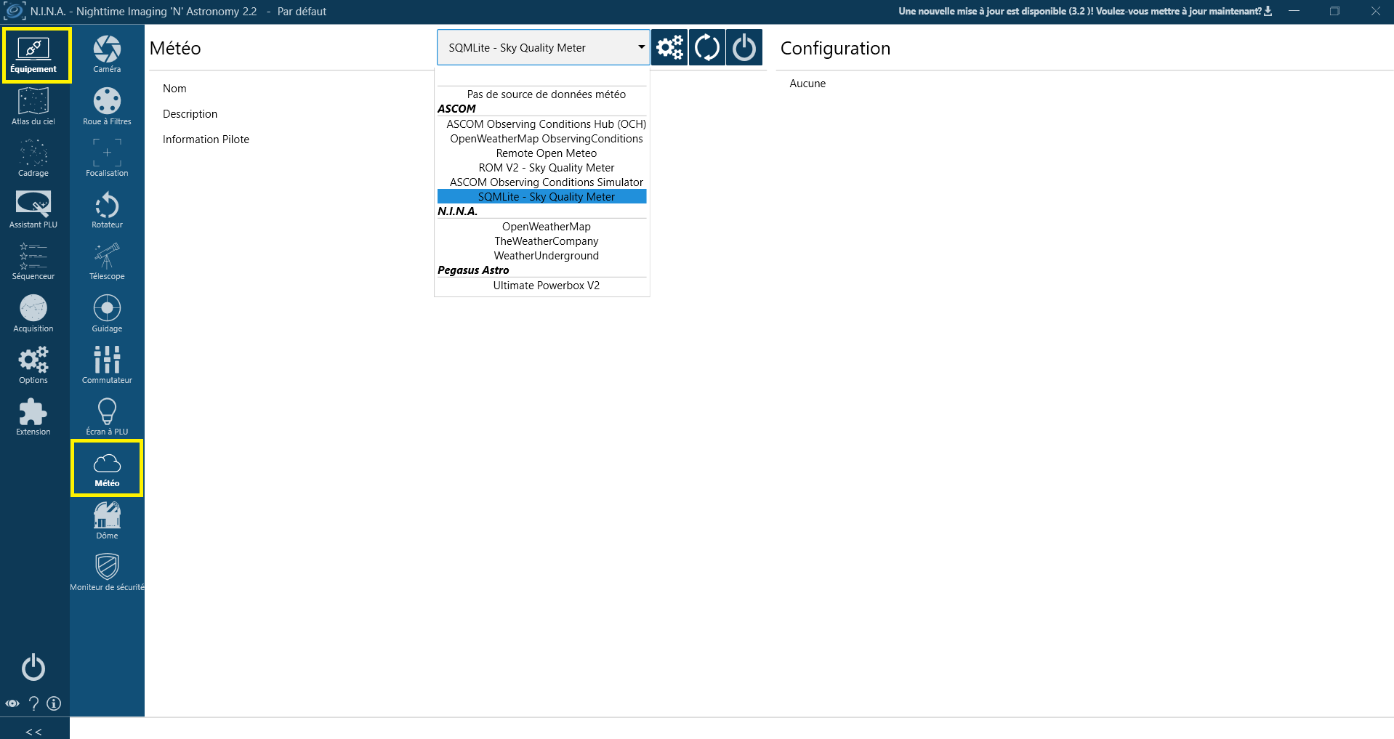
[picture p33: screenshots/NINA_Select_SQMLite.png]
NINA Sélection SQMLite


<p align="right"><a href="#sommaire">Retour au sommaire</a></p>

#### Première utilisation dans NINA

Lors de la première utilisation dans N.I.N.A., un appairage du **SQMLite** est nécessaire.\
Pour cela, cliquez sur le bouton "***Paramètres***".

NINA SQMLite settings

Dans la boîte de dialogue qui s'ouvre, sélectionnez le périphérique "***SQM Lite***" détecté puis validez.

Driver Setup Dialog

> [!NOTE]
> Voilà, l'appairage est effectué. Il ne sera plus nécessaire d'effectuer cette opération lors des prochaines utilisations.

<p align="right"><a href="#sommaire">Retour au sommaire</a></p>

Voilà, vous pouvez désormais profiter des données du **SQMLite - Sky Quality Meter** dans NINA.\
Enjoy

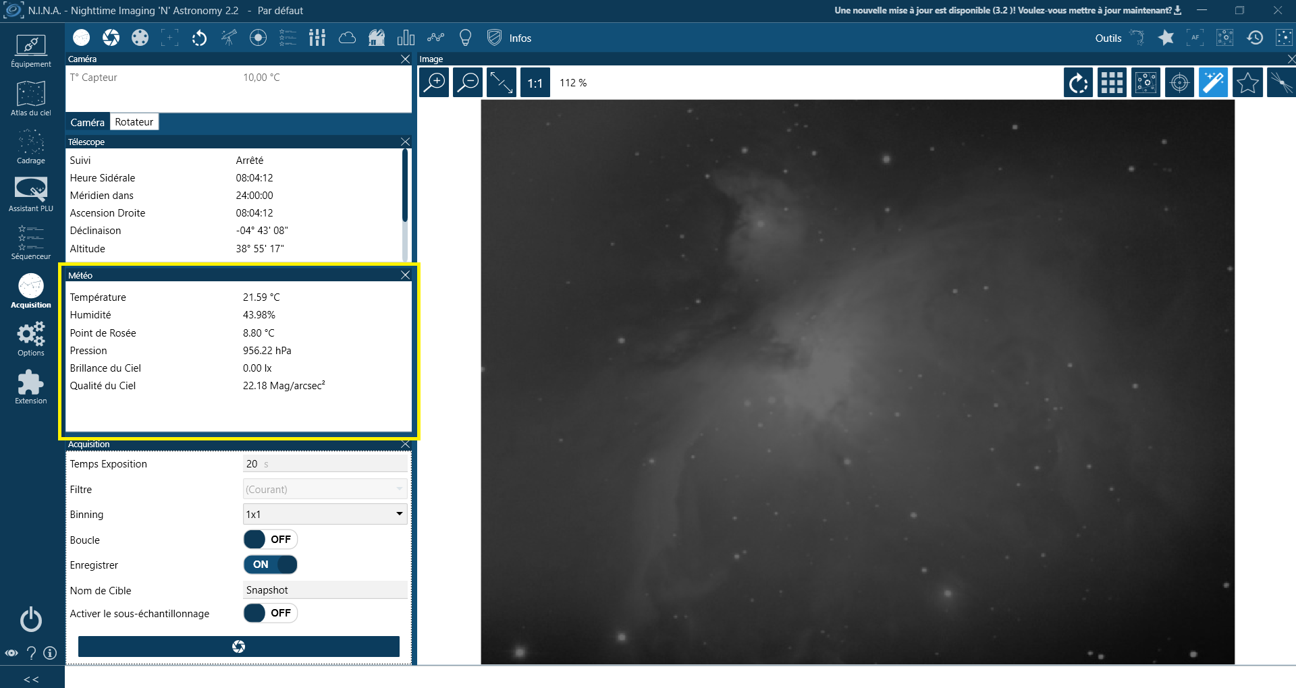
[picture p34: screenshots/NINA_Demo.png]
NINA démo


<p align="right"><b><i>Juanito del Pepito</i></b></p>

## Retex

Voici un petit retour d'expérience des mesures de l'état de mon ciel à mon domicile :

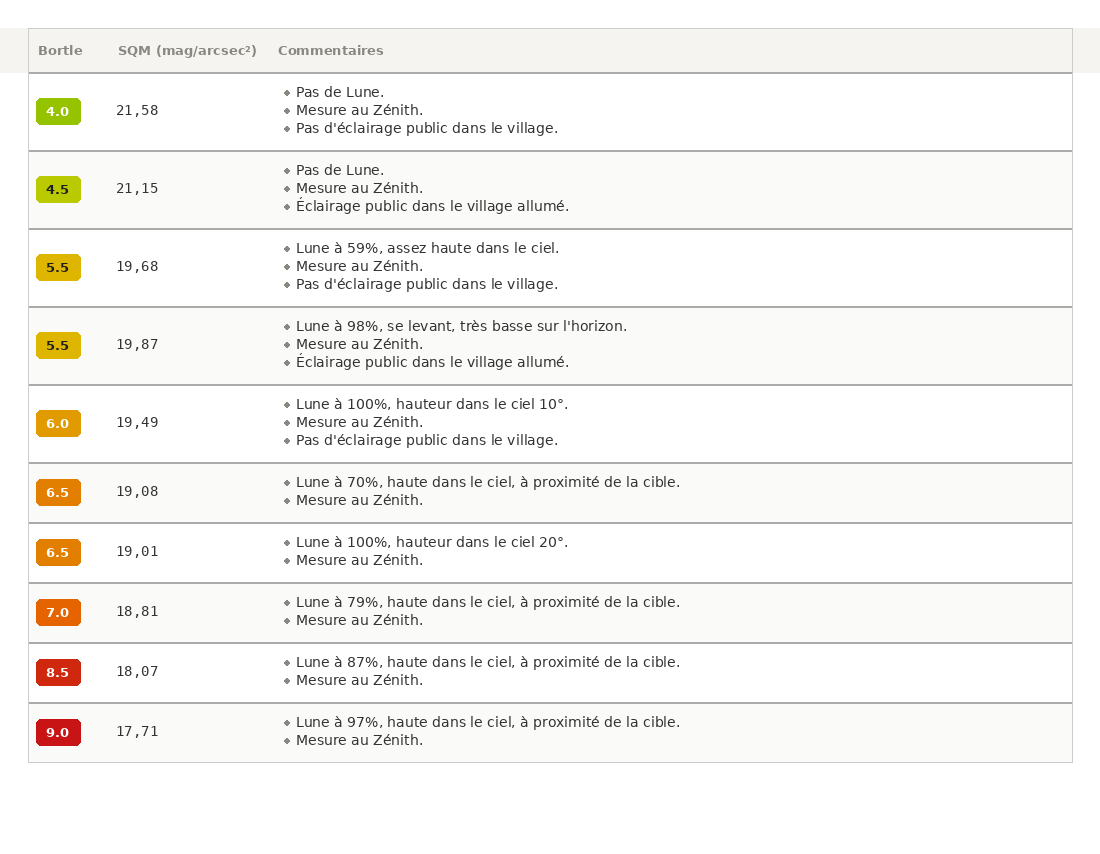
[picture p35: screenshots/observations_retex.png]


## Révisions

| Date | Version | Commentaires |
| --- | --- | --- |
| 31/05/2026 | 2.0.1.0 | Version initiale |

<p align="right"><a href="#sommaire">Retour au sommaire</a></p>

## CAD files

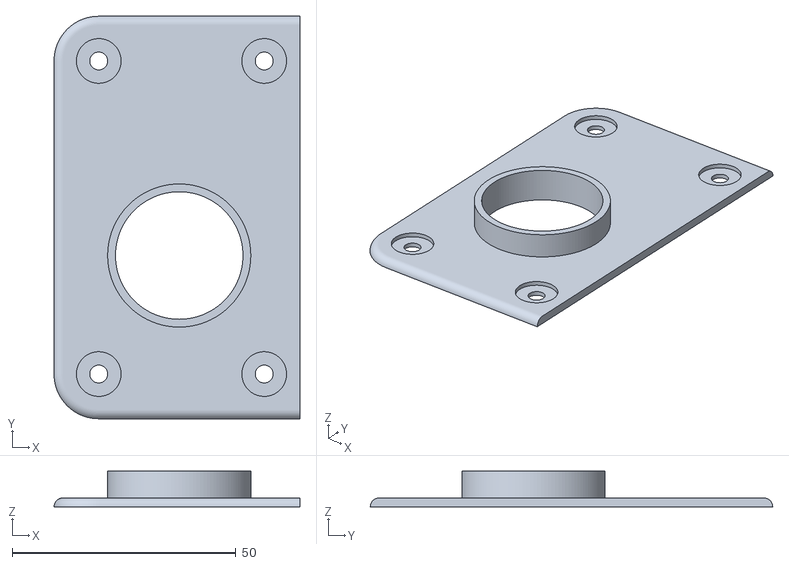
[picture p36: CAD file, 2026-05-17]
Boxes/SQMLITE_TopHigh.stl
55.0 x 90.0 x 8.00

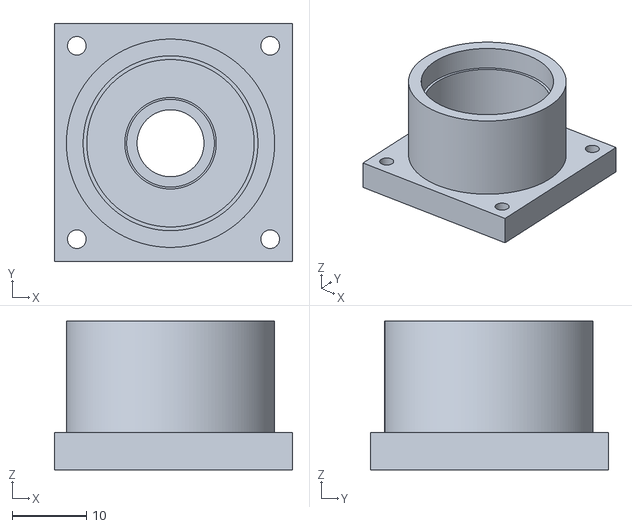
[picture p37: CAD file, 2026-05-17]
Boxes/SQMLITE_TSL2591_Enclosure.stl
32.0 x 32.0 x 20.0

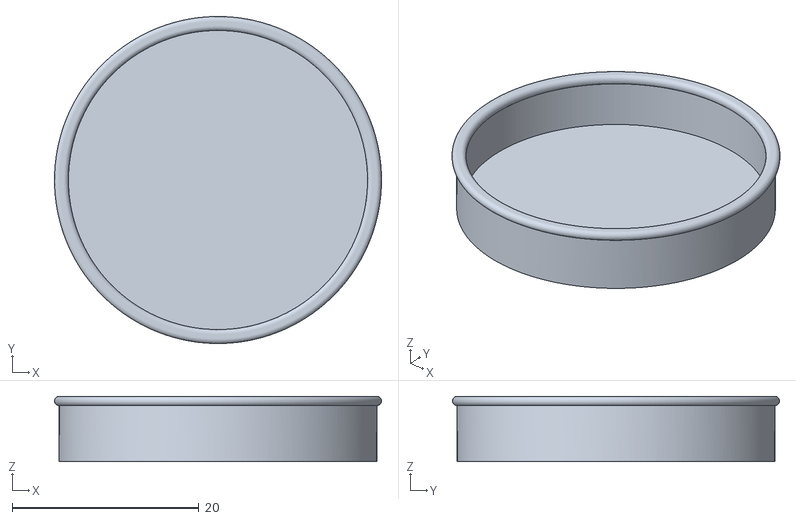
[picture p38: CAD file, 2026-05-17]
Boxes/SQMLITE_Tube28_Cover_TPU.stl
35.0 x 35.0 x 7.00

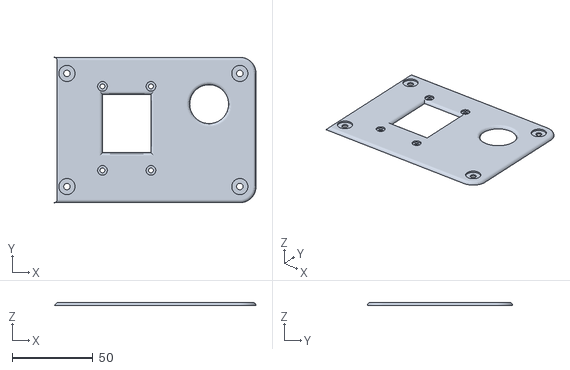
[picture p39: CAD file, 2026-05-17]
Boxes/SQMLITE_TopLow.stl
125.0 x 90.0 x 2.00

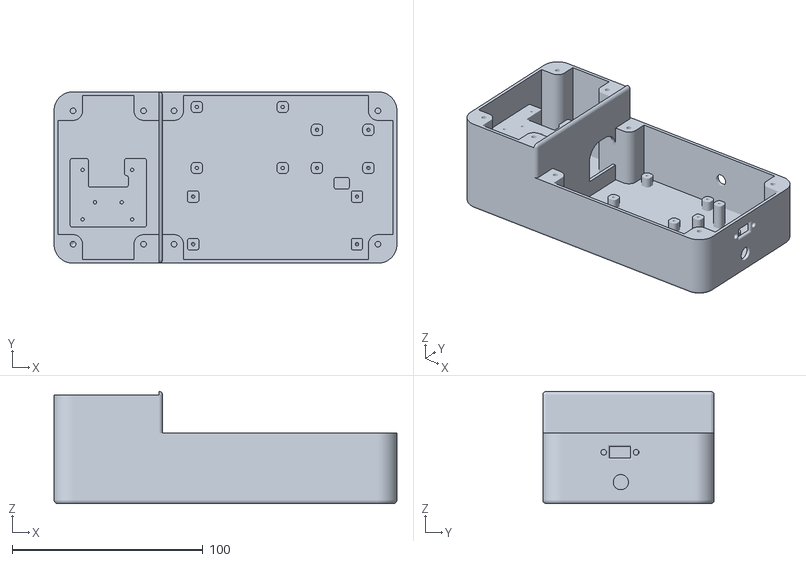
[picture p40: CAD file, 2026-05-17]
Boxes/SQMLITE_Bottom.stl
180.0 x 90.0 x 59.0

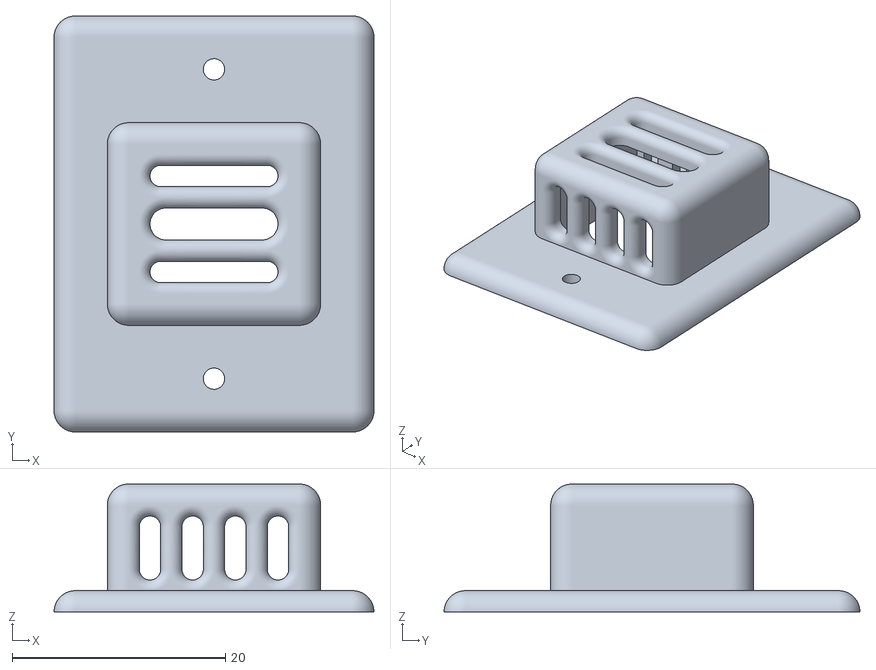
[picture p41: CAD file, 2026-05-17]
Boxes/SQMLITE_Sensor.stl
30.0 x 39.0 x 12.0

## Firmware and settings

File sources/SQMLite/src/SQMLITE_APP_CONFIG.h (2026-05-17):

/// ---------------------------------------------------------------------
///
/// Projet                          : SQM Lite - Sky Quality Meter
/// Auteur                          : Juanito del Pepito
/// Version                         : 2.0.1.0
/// Date                            : 31/05/2026
/// 
/// Description                     : Sky Quality Meter (SQM) - Fichier de configuration de l'application
/// Gitub                           : https://github.com/Juani005999/SQMLite
/// Licence							: GPL-3.0 license
///
/// Capteurs et périphériques       : Cette application utilise les capteurs et périphériques suivant
///										- TSL2591
///										- BME280
///										- TFT ST7735
/// 
/// Prérequis                       : Cette application nécessite l'ajout des bibliothèques suivantes
///										- Adafruit_TSL2591
///										- Adafruit_BME280
///										- TFT_eSPI
/// 
/// ---------------------------------------------------------------------
#pragma once

// Include des librairies
#include "JUANITO_APP.h"
#include "JUANITO_MOVING_AVERAGE.h"
#include <SQMLITE_APP_ICONS.h>
#include <Adafruit_BME280.h>
#include <Adafruit_TSL2591.h>
#include <TFT_eSPI.h>
#include <BLEDevice.h>
#include <BLEServer.h>
#include <BLEUtils.h>
#include <BLE2902.h>

// Définition des constantes correspondant aux PIN
#define ESP32_GPIO_SDA                          21                      // GPIO I2C SDA
#define ESP32_GPIO_SCL                          22                      // GPIO I2C SCL
#define JOYSTICK_PIN_SWITCH                     25                      // Joystick Switch
#define JOYSTICK_PIN_X                          32                      // Joystick X
#define JOYSTICK_PIN_Y                          33                      // Joystick Y

// Définition des constantes correspondant aux paramètres des capteurs
#define BME280_I2C_ADDRESS                      0x76                    // Sensor T/P/H BME280
#define TSL2591_NUMBER_ID                       2591                    // Identifiant du TSL2591

// Définition des constantes correspondant aux intervalles
#define READ_ENVIRONMENT_INTERVAL               3000                    // Intervalle de lecture de l'environnement via BME280
#define READ_LUX_INTERVAL                       5000					// Intervalle de lecture de la luminosité via TSL2591
#define BLE_NOTIFY_INTERVAL						1000					// Intervalle de Notification des caractéristiques BLE (Bluetooth Low Energy)
#define DISPLAY_INTERVAL                        120                     // Intervalle d'affichage sur l'écran
#define JOYSTICK_BUTTON_LONG_INTERVAL           1000					// Intervalle du clic long sur le Joystick
#define JOYSTICK_READ_INTERVAL					50						// Intervalle de lecture de l'état du Joystick

// Définition des constantes de taille pour les chaînes de caractères
#define BT_CMD_LINE_LENGTH                      256                     // Taille max d'une commande Bluetooth

// Définition des constantes pour la calibration de la lecture du TSL2591
#define TSL2591_SENSOR_VALUE_LOW				750						// Niveau bas du sensor => augmentation de la sensibilité du sensor si valeur en dessous
#define TSL2591_SENSOR_VALUE_HIGH				20000					// Niveau haut du sensor => diminution de la sensibilité du sensor si valeur au dessus
#define TSL2591_CALIBRATION						0						// Valeur servant à la calibration du TSL2591 : le calcul donne 1.121, la pratique donne 0
#define MIN_LUX_THRESHOLD						0.00005f				// Seuil minimum de lux valide (en dessous = bruit capteur)
#define TSL2591_MOVING_AVERAGE_COUNT			50						// Nombre de valeurs pour le calcul de la moyenne mobile du Lux
#define TSL2591_CORRECTION_TEMP_COEFF			-0.002f					// Coefficient thermique /°C
#define TSL2591_CORRECTION_TEMP_REF_C			25.0f					// Température de référence (°C)

// Définition des constantes pour la communication Bluetooth Low Energy (BLE)
#define BLE_DEVICE_NAME							"SQM Lite"
#define BLE_SERVICE_UUID						"d45872d6-b482-488e-b620-a0bb4a9c4d86"
#define BLE_CHARACTERISTIC_UUID_TEMPERATURE		"fd1839f2-f064-4f47-9e18-d212cbe538a9"
#define BLE_CHARACTERISTIC_UUID_HUMIDITY		"634fb69b-62b4-4fec-bce9-bc70e6b8166c"
#define BLE_CHARACTERISTIC_UUID_PRESSURE		"b8e5b7e1-4693-40e7-adbf-7784299e3b51"
#define BLE_CHARACTERISTIC_UUID_DEWPOINT		"41ce96a2-b73b-46be-90be-34e5dcd59c56"
#define BLE_CHARACTERISTIC_UUID_SKYBRIGHTNESS	"6fcf4961-63d5-4a3c-9b4a-60163aefa479"
#define BLE_CHARACTERISTIC_UUID_SKYQUALITY		"09c6e80f-55ed-4d70-bff2-62fc6ba07b3e"
#define BLE_CHARACTERISTIC_NUMHANDLES_COUNT		32						// Nombre de Handles nécessaires pour les caractéristiques du service BLE
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

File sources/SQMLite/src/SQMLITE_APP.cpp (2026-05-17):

#include <SQMLITE_APP.h>

/// <summary>
/// Constructeur
/// </summary>
SQMLITE_APP::SQMLITE_APP()
{
}

/// <summary>
/// Initialisation de l'App
/// </summary>
void SQMLITE_APP::Init()
{
	// Positionnement des PIN
	pinMode(JOYSTICK_PIN_SWITCH, INPUT_PULLUP);
	digitalWrite(JOYSTICK_PIN_SWITCH, HIGH);
	
	// Initialisation Wire avec définition des PIN SDA/SCL
	Wire.setPins(ESP32_GPIO_SDA, ESP32_GPIO_SCL);

	// Initialisation des objets représentant les capteurs et périphériques
	_tft.Init(&_dataEnvironment, &_dataLuminosity, &_bluetoothConnected);
	_bme280.Init(&_dataEnvironment);
	_tsl2591.Init(&_tft, &_dataLuminosity, &_dataEnvironment);
	_bluetoothLE.Init(&_bluetoothConnected, &_dataEnvironment, &_dataLuminosity);
	_tsl2591.StartTask();

	// Initialisation Chronos
	_chronoReadJoystick = 0;
	_chronoJoystickButtonPressed = 0;
	_chronoDisplayTimeout = millis();

	// Initialisation des performances pour les traces
	InitAppPerformances();
}

/// <summary>
/// Processus complet a exécuter lors d'un Loop
/// </summary>
void SQMLITE_APP::Loop()
{
	// Lecture de l'état du Joystick
	ReadJoystickState();

	// Lecture température, humidité, pression atm. et point de rosée
	_bme280.ReadEnvironment();

	// Lecture Luminosité
	_tsl2591.ReadLuminosity();

	// Envoi des notifications des caractéristiques du BLE (Bluetooth Low Energy)
	_bluetoothLE.Notify();

	// Actualisation du display
	UpdateCurrentDisplay();
	_tft.SetCurrentDisplay(_currentDisplayScreenType, _displayHomeType);
	_tft.UpdateDisplay();

	// Trace des performances
	TraceAppPerformances();
}

/// <summary>
/// Lecture de l'état du Joystick
/// </summary>
void SQMLITE_APP::ReadJoystickState()
{
	// Lecture de l'état du Joystick sur intervalle
	if (millis() > _chronoReadJoystick + JOYSTICK_READ_INTERVAL)
	{
		// Bouton du Joystick
		if (digitalRead(JOYSTICK_PIN_SWITCH) == LOW)
		{
			// Actualisation Chrono et Flag
			if (!_joystickPressed)
			{
				_chronoJoystickButtonPressed = millis();
			}
			_joystickPressed = true;

			// Clic long
			if (millis() > _chronoJoystickButtonPressed + JOYSTICK_BUTTON_LONG_INTERVAL)
			{
				_currentAction = ACTION_CLICK_LONG;
				// Actualisation des Flags
				_joystickPressed = false;
				// Trace
				debugln(F(""));
				debugln(F("[ACTION] Long Click"));
			}
		}
		// Pour le bouton Joystick, on traite le clic court sur relachement du bouton
		else
		{
			if (_joystickPressed && _currentDisplayScreenType != DISPLAY_NONE)
			{
				_currentAction = ACTION_CLICK;
				debugln(F(""));
				debugln(F("[ACTION] Click"));
			}
			// Actualisation des Flags
			_joystickPressed = false;
		}

		// Position du Joystick :
		// - Pas de lecture si le bouton du Joystick est pressé, afin de réduire les miss clicks
		if (!_joystickPressed)
		{
			int x = analogRead(JOYSTICK_PIN_X);
			int y = analogRead(JOYSTICK_PIN_Y);

			if (y > JOYSTICK_POSITION_MIN_VALUE_HIGH && !_joystickMoved)
			{
				_joystickMoved = true;
				_currentAction = ACTION_LEFT;
				debugln(F(""));
				debugln(F("[ACTION] Left"));
			}
			else if (y < JOYSTICK_POSITION_MIN_VALUE_LOW && !_joystickMoved)
			{
				_joystickMoved = true;
				_currentAction = ACTION_RIGHT;
				debugln(F(""));
				debugln(F("[ACTION] Right"));
			}
			else if (x > JOYSTICK_POSITION_MIN_VALUE_HIGH && !_joystickMoved)
			{
				_joystickMoved = true;
				_currentAction = ACTION_DOWN;
				debugln(F(""));
				debugln(F("[ACTION] Down"));
			}
			else if (x < JOYSTICK_POSITION_MIN_VALUE_LOW && !_joystickMoved)
			{
				_joystickMoved = true;
				_currentAction = ACTION_UP;
				debugln(F(""));
				debugln(F("[ACTION] Up"));
			}
			else
			{
				if (x < JOYSTICK_POSITION_MIN_VALUE_HIGH
					&& x > JOYSTICK_POSITION_MIN_VALUE_LOW
					&& y < JOYSTICK_POSITION_MIN_VALUE_HIGH
					&& y > JOYSTICK_POSITION_MIN_VALUE_LOW)
					_joystickMoved = false;
				// String trace = "X : " + String(x) + " / Y : " + String(y);
				// debugln(trace);
			}
		}

		// Si une action est en cours, on force la mise à jour complète de l'affichage
		if (_currentAction != ACTION_NONE)
		{
			_tft.ForceRedraw();
		}

		// Actualisation Chrono
		_chronoReadJoystick = millis();
	}
}

/// <summary>
/// Actualise l'affichage en cours sur action du Joystick
/// </summary>
void SQMLITE_APP::UpdateCurrentDisplay()
{
	// Gestion de la mise en veille de l'affichage
	if (_currentAction == ACTION_NONE && millis() > _chronoDisplayTimeout + SCREEN_TIMEOUT)
	{
		_currentDisplayScreenType = DISPLAY_NONE;
	}

	// On ne fait rien si pas d'actions en cours
	if (_currentAction != ACTION_NONE)
	{
		// Si l'affichage est en mode veille, on le sort de la veille
		if (_currentDisplayScreenType == DISPLAY_NONE)
		{
			_currentDisplayScreenType = DISPLAY_HOME;
		}
		// Sinon, on positionne l'affichage en fonction de l'action en cours
		else
		{
			// En fonction de l'action en cours
			switch (_currentAction)
			{
				case ACTION_RIGHT:
					if (_currentDisplayScreenType == DISPLAY_ENVIRONMENT)
					{
						_currentDisplayScreenType = DISPLAY_HOME;
					}
					else
					{
						_currentDisplayScreenType = static_cast<DISPLAY_SCREEN_TYPE>(static_cast<int>(_currentDisplayScreenType) + 1);
					}
					break;

				case ACTION_LEFT:
					if (_currentDisplayScreenType == DISPLAY_HOME)
					{
						_currentDisplayScreenType = DISPLAY_ENVIRONMENT;
					}
					else
					{
						_currentDisplayScreenType = static_cast<DISPLAY_SCREEN_TYPE>(static_cast<int>(_currentDisplayScreenType) - 1);
					}
					break;

				case ACTION_CLICK:
					if (_currentDisplayScreenType == DISPLAY_HOME)
					{
						if (_displayHomeType == DISPLAY_HOME_SQM)
						{
							_displayHomeType = DISPLAY_HOME_LUX;
						}
						else
						{
							_displayHomeType = DISPLAY_HOME_SQM;
						}
					}
					else if (_currentDisplayScreenType == DISPLAY_LUX)
					{
						_tsl2591.ClearLuxAverage();
					}
					break;

				case ACTION_CLICK_LONG:
					_currentDisplayScreenType = DISPLAY_NONE;
					break;

				case ACTION_UP:
				case ACTION_DOWN:
					_currentDisplayScreenType = DISPLAY_HOME;
					break;

				case ACTION_NONE:
				default:
					break;
			}
		}

		// Trace
		debugln(F(""));
		debug(F("[DISPLAY] ScreenType: "));
		debug(_currentDisplayScreenType);
		debug(F(" / HomeType: "));
		debugln(_displayHomeType);

		// RAZ de l'état de l'action en cours
		_currentAction = ACTION_NONE;
		// Sur action, RAZ du compteur de veille en cours
		_chronoDisplayTimeout = millis();
	}
}

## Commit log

2026-05-17 Sources and Boxes
    [SQMLITE_Bottom.stl, SQMLITE_Sensor.stl, SQMLITE_TSL2591_Enclosure.stl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]
2026-05-18 Update des liens de pièces
